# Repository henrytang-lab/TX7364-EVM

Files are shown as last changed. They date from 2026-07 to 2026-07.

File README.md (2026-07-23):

The TX7364EVM is used for the evaluation of TX7364 
device under various drive strength, different voltage 
levels and different modes of the device. The EVM 
contains all necessary control signals and on-board 
power generation, which greatly reduces the need 
for external equipment. The evaluation system also 
includes GUI software for Microsoft® Windows® for 
easily programming various modes and patterns into 
the device.
Features
• Allows control of TX7364 device using simple GUI 
via USB
• B-mode or CW mode of transmit can be 
programmed
• Multiple pattern and Delay profiles can be stored, 
and user can switch between them easily in GUI
• Clock and Sync generator present on board
• Sync frequency can be changed using onboard 
potentiometer
• Option to give external sync
• Uses CMOS serial programming interface
• Error flag register to detect faulty conditions and 
automatic thermal shutdown
• Evaluate Transmit Performance with 100pF||1kΩ 
load



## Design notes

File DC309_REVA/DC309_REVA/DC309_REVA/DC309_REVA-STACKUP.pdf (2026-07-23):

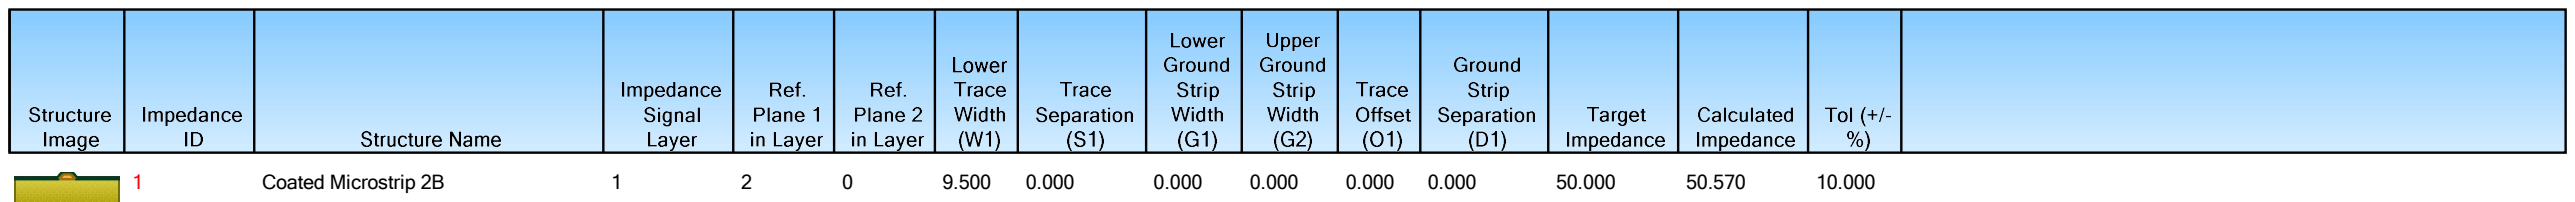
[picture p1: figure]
Coated Microstrip 2B

StackName: Master
Version:
Date: 17-05-2022
Author:
Department:
Site:
Associated Documents: | Revision: | Modification: | Date of Revision: | Editor

Page
1/2
Copyright © | Print style & presentation copyright © Polar Instruments Ltd
Electra | Liquid PhotoImageable Mask | SolderMask | 2.000 | 4.100
1 | Copper Foil | Copper | 1.881 | 100.000 | 1, 2
ISOLA | ISOLA-370HR | PrePreg 2113 | FR4 | 3.405 | 4.040
ISOLA | ISOLA-370HR | PrePreg 1080 | FR4 | 2.649 | 3.900
2 | 0.700 | 65.000
ISOLA | ISOLA-370HR | Core | FR4 | 5.000 | 4.040
3 | 0.700 | 35.000 | 3, 4
ISOLA | ISOLA-370HR | PrePreg 1080 | FR4 | 2.406 | 3.900
ISOLA | ISOLA-370HR | PrePreg 1080 | FR4 | 2.406 | 3.900
4 | 0.700 | 65.000
ISOLA | ISOLA-370HR | Core | FR4 | 5.000 | 4.040
5 | 0.700 | 35.000 | 5, 6
ISOLA | ISOLA-370HR | PrePreg 1080 | FR4 | 2.406 | 3.900
ISOLA | ISOLA-370HR | PrePreg 1080 | FR4 | 2.406 | 3.900
6 | 0.700 | 65.000
ISOLA | ISOLA-370HR | Core | FR4 | 4.000 | 4.300
7 | 0.700 | 65.000
ISOLA | ISOLA-370HR | PrePreg 1080 | FR4 | 2.406 | 3.900
ISOLA | ISOLA-370HR | PrePreg 1080 | FR4 | 2.406 | 3.900
8 | 0.700 | 35.000 | 7, 8
ISOLA | ISOLA-370HR | Core | FR4 | 5.000 | 4.040
9 | 0.700 | 65.000
ISOLA | ISOLA-370HR | PrePreg 1080 | FR4 | 2.406 | 3.900
ISOLA | ISOLA-370HR | PrePreg 1080 | FR4 | 2.406 | 3.900
10 | 0.700 | 35.000 | 9, 10
ISOLA | ISOLA-370HR | Core | FR4 | 5.000 | 4.040
11 | 0.700 | 65.000
ISOLA | ISOLA-370HR | PrePreg 1080 | FR4 | 2.649 | 3.900
ISOLA | ISOLA-370HR | PrePreg 2113 | FR4 | 3.405 | 4.040
12 | Copper Foil | Copper | 1.881 | 100.000 | 11, 12
Electra | Liquid PhotoImageable Mask | SolderMask | 2.000 | 4.100 ⁷⁰.12 | 66.12
2 | Edge Coupled Coated Microstrip 2B | 1 | 2 | 0 | 9.000 | 18.000 | 0.000 | 0.000 | 0.000 | 0.000 | 100.000 | 98.110 | 10.000

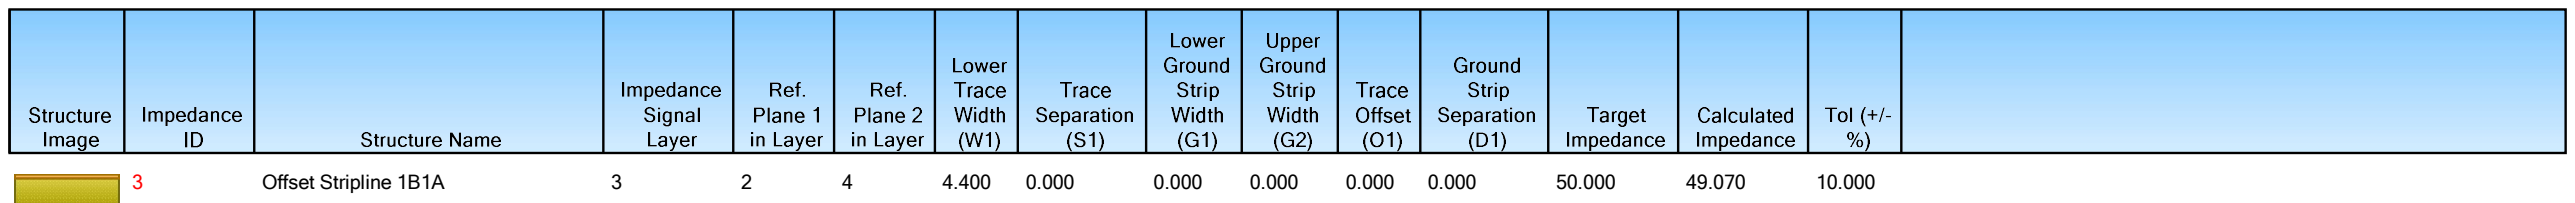
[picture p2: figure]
Offset Stripline 1B1A

StackName:
Version:
Date: 17-05-2022
Author:
Department:
Site:
Associated Documents: | Revision: | Modification: | Date of Revision: | Editor

Page
2/2
Copyright © | Print style & presentation copyright © Polar Instruments Ltd
4 | Edge Coupled Offset Stripline 1B1A | 3 | 2 | 4 | 4.000 | 8.000 | 0.000 | 0.000 | 0.000 | 0.000 | 100.000 | 98.650 | 10.000
5 | Offset Stripline 1B1A | 5 | 4 | 6 | 4.400 | 0.000 | 0.000 | 0.000 | 0.000 | 0.000 | 50.000 | 49.070 | 10.000
6 | Edge Coupled Offset Stripline 1B1A | 5 | 4 | 6 | 4.000 | 8.000 | 0.000 | 0.000 | 0.000 | 0.000 | 100.000 | 98.650 | 10.000
7 | Edge Coupled Offset Stripline 1B1A | 8 | 7 | 9 | 4.000 | 8.000 | 0.000 | 0.000 | 0.000 | 0.000 | 100.000 | 98.650 | 10.000
8 | Offset Stripline 1B1A | 8 | 7 | 9 | 4.400 | 0.000 | 0.000 | 0.000 | 0.000 | 0.000 | 50.000 | 49.070 | 10.000
9 | Edge Coupled Offset Stripline 1B1A | 10 | 9 | 11 | 4.000 | 8.000 | 0.000 | 0.000 | 0.000 | 0.000 | 100.000 | 98.650 | 10.000
10 | Offset Stripline 1B1A | 10 | 9 | 11 | 4.400 | 0.000 | 0.000 | 0.000 | 0.000 | 0.000 | 50.000 | 49.070 | 10.000
11 | Edge Coupled Coated Microstrip 2B | 12 | 11 | 0 | 9.000 | 18.000 | 0.000 | 0.000 | 0.000 | 0.000 | 100.000 | 98.110 | 10.000
12 | Coated Microstrip 2B | 12 | 11 | 0 | 9.500 | 0.000 | 0.000 | 0.000 | 0.000 | 0.000 | 50.000 | 50.570 | 10.000
1 | 12 | 1 | Mechanical PTH

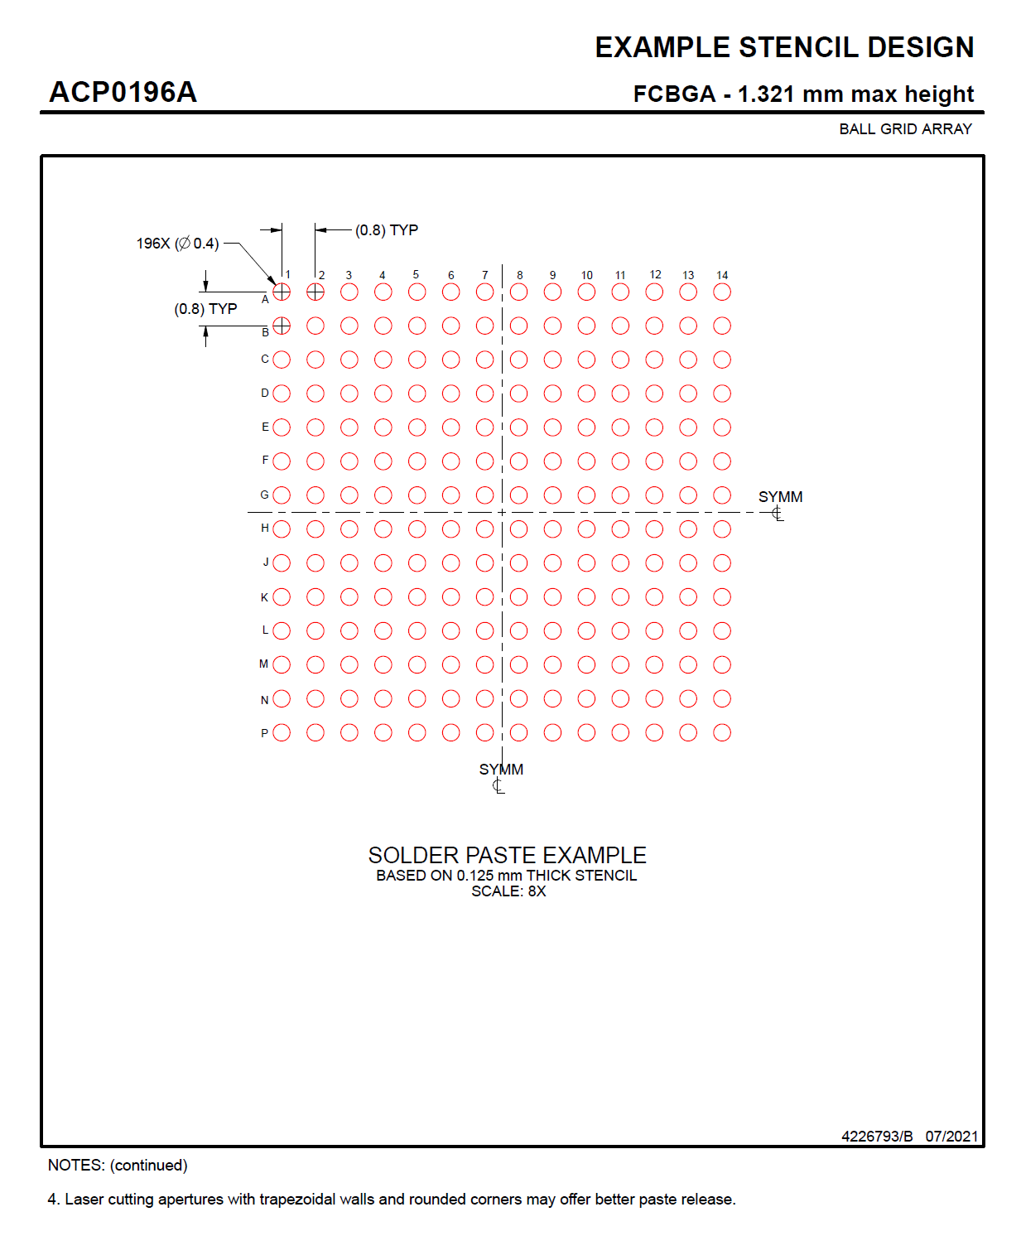
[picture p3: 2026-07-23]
Stencil_Design.PNG

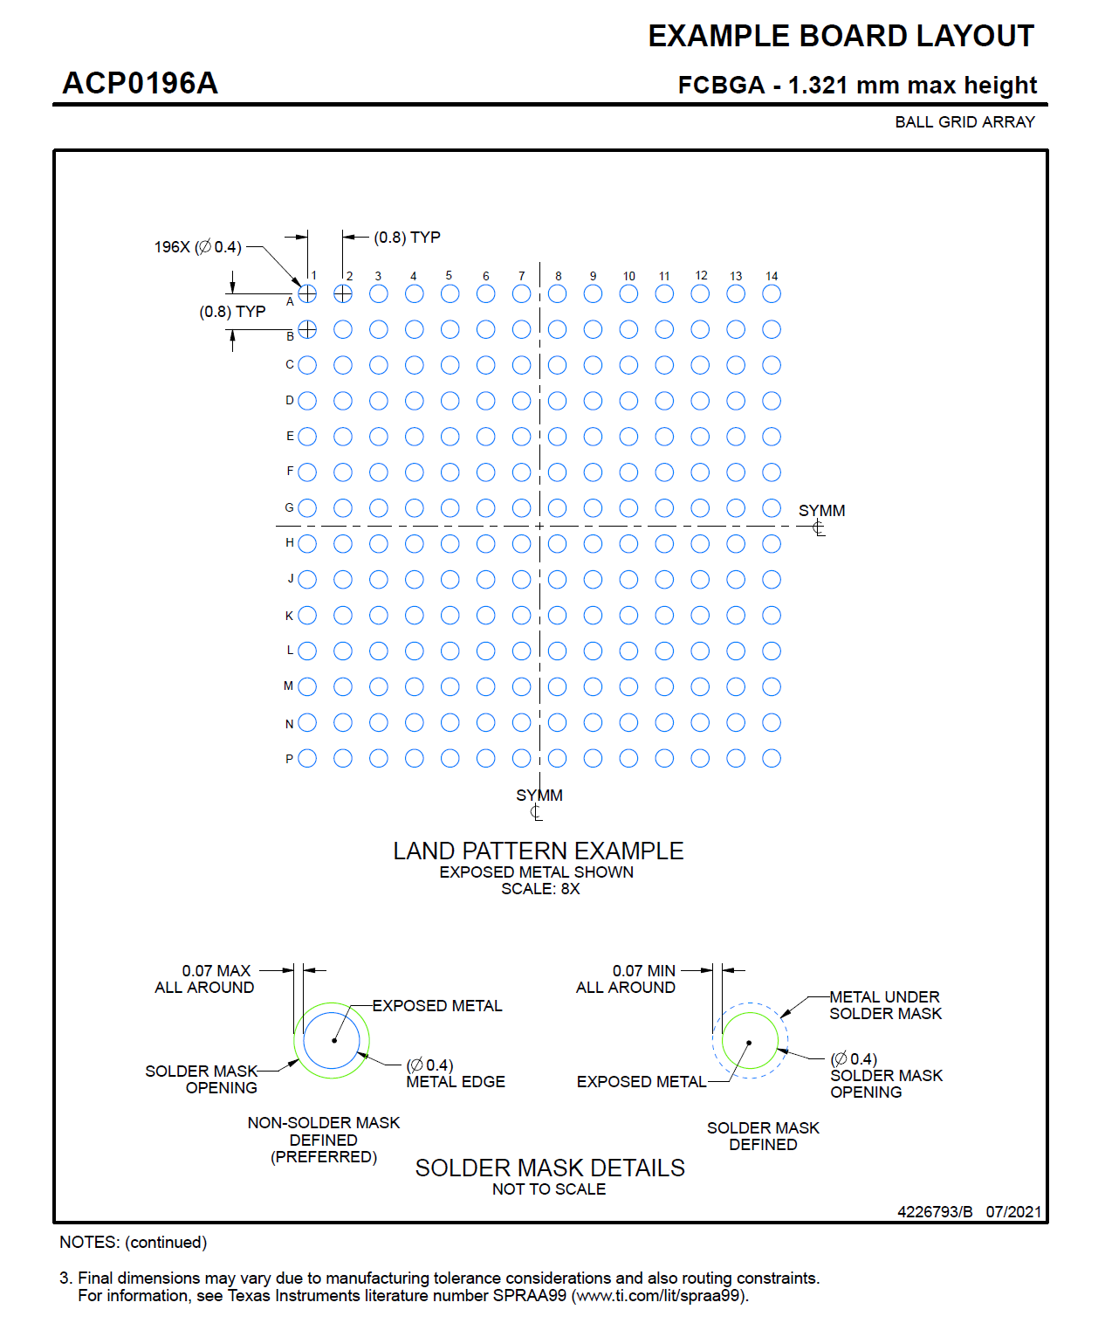
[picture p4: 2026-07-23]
Example_Board_Layout.PNG

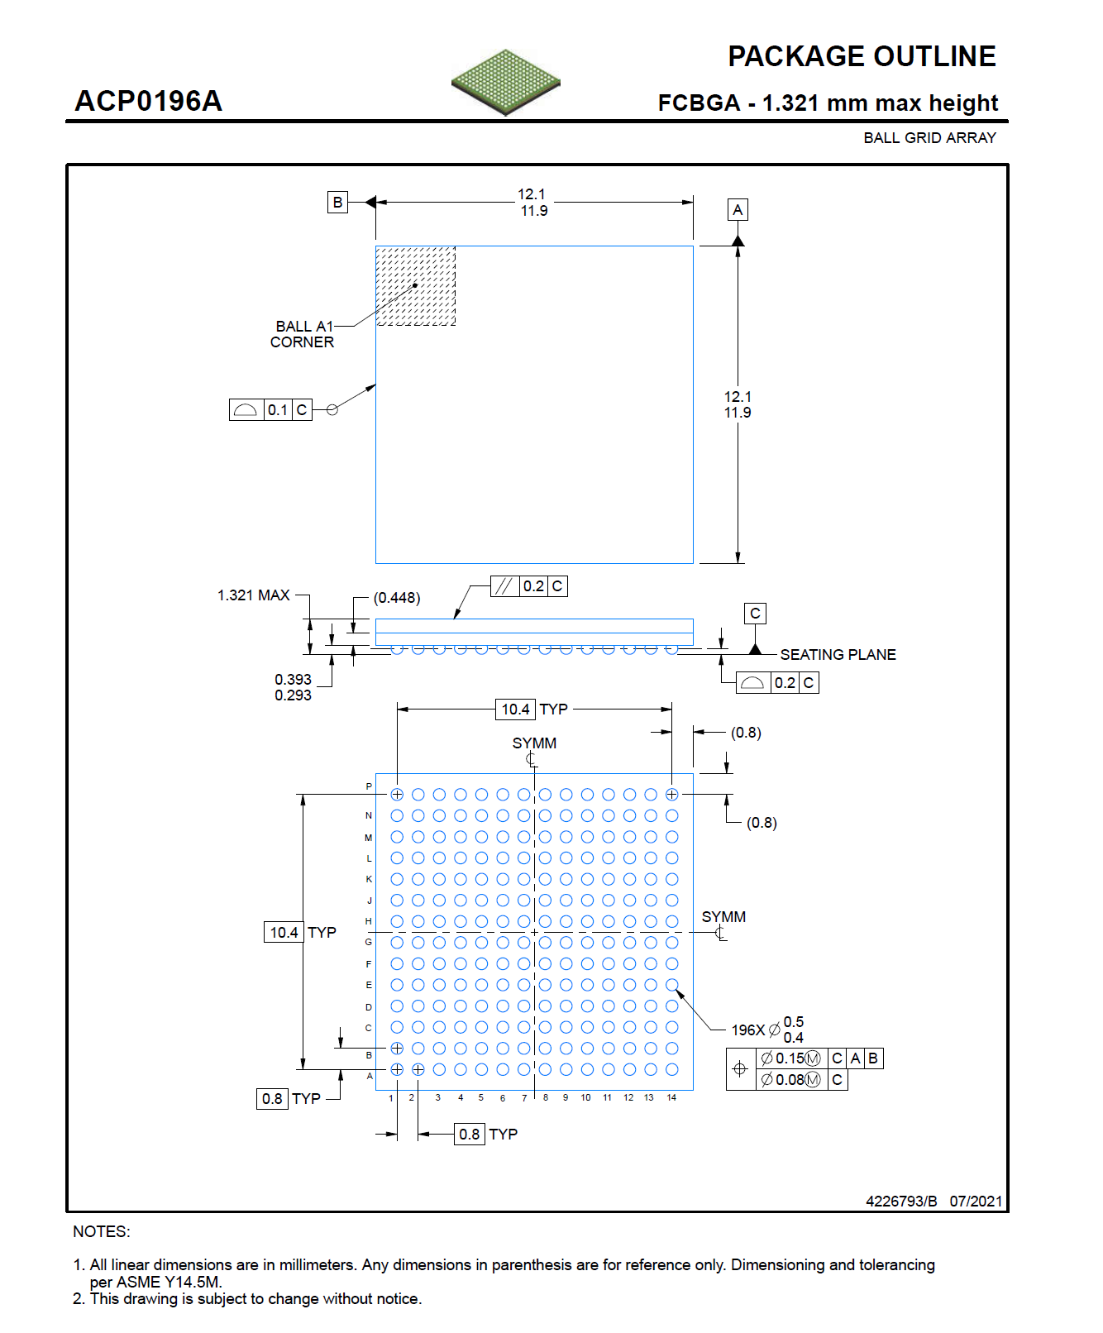
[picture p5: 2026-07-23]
Package_Outline.PNG

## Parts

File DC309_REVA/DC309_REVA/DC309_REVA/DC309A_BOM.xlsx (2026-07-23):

Filename: | #VALUE! |  |  |  | DC309
Variant: | Compact |  |  |  | A
Generated: | 2/14/2024 12:07 PM
TID #: | N/A |  |  |  | DC309 REV A Bill of Materials
Item # | Designator | Quantity | Value | PartNumber | Manufacturer | Description | PackageReference
1 | !PCB1 | 1 |  | DC309 | Any | Printed Circuit Board
2 | C1, C211, C212, C285, C286 | 5 | 0.1uF | GRM155R71C104KA88D | MuRata | CAP, CERM, 0.1 uF, 16 V, +/- 10%, X7R, 0402 | 0402
3 | C2, C5, C6, C22, C71, C72, C73, C74, C75, C76, C77, C78, C79, C80, C81, C82, C83, C84, C86, C87, C88, C89, C90, C91, C92, C93, C94, C95, C96, C97, C98, C174, C175, C177, C178, C179, C180, C181, C182, C183, C184, C185, C186, C187, C188, C189, C190, C191, C193, C194, C195, C196, C197, C198, C199, C200, C201, C202, C203, C204, C205, C207, C213, C215 | 64 | 20pF | C0402C200J5GACTU | Kemet | CAP, CERM, 20 pF, 50 V, +/- 5%, C0G/NP0, 0402 | 0402
4 | C3, C7 | 2 | 10uF | 200LLE10MEFC8X11.5 | Rubycon | CAP, AL, 10 uF, 200 V, +/- 20%, TH | RCAP_8x11.5mm
5 | C4, C8 | 2 | 0.1uF | C1206C104K2RACTU | Kemet | CAP, CERM, 0.1 uF, 200 V, +/- 10%, X7R, 1206 | 1206
6 | C9, C20 | 2 | 10uF | EEE-FK1V100R | Panasonic | CAP, AL, 10 uF, 35 V, +/- 20%, 0.7 ohm, AEC-Q200 Grade 2, SMD | SMT Radial C
7 | C10, C14, C16, C18, C21, C23, C31, C35, C36, C46, C50, C53, C99, C100, C103, C104, C105, C106, C107, C120, C126, C127, C128, C136, C138, C149, C150, C161, C167, C168, C171, C250, C279, C280, C283 | 35 | 0.1uF | 0402YC104KAT2A | AVX | CAP, CERM, 0.1 uF, 16 V, +/- 10%, X7R, 0402 | 0402
8 | C11, C12, C13, C37, C170 | 5 | 4.7pF | 06035A4R7CAT2A | AVX | CAP, CERM, 4.7 pF, 50 V, +/- 5%, C0G/NP0, 0603 | 0603
9 | C15, C17, C19, C49, C172 | 5 | 4.7uF | C0805C475K3PACTU | Kemet | CAP, CERM, 4.7 uF, 25 V, +/- 10%, X5R, 0805 | 0805
10 | C24, C70, C85, C151, C153, C155, C157, C176, C192, C206, C208, C209, C210, C214, C216, C217, C218, C219, C220, C221, C222, C223, C224, C225, C226, C227, C228, C229, C230, C231, C232, C233, C234, C235, C236, C237, C238, C239, C240, C241, C242, C243, C244, C245, C246, C247, C248, C249, C251, C252, C253, C254, C255, C256, C257, C258, C259, C260, C261, C262, C263, C264, C265, C266 | 64 | 100pF | AC0603JRNPOYBN101 | Yageo | CAP, CERM, 100 pF, 250 V,+/- 5%, C0G/NP0, AEC-Q200 Grade 1, 0603 | 0603
11 | C25 | 1 | 10uF | GRM188R60J106ME47D | MuRata | CAP, CERM, 10 uF, 6.3 V, +/- 20%, X5R, 0603 | 0603
12 | C26, C27 | 2 | 0.01uF | 520L103KT16T | AT Ceramics | CAP, CERM, 0.01 uF, 16 V, +/- 10%, X7R, 0402 | 0402
13 | C28, C38, C39, C40, C41, C42, C43, C44, C57, C58, C59, C60, C61, C62, C66, C67 | 16 | 0.1uF | C2012X7T2E104K125AA | TDK | CAP, CERM, 0.1 uF, 250 V, +/- 10%, X7T, 0805 | 0805
14 | C29, C166, C169, C277 | 4 | 0.1uF | C1005X5R0J104K050BA | TDK | CAP, CERM, 0.1 uF, 6.3 V, +/- 10%, X5R, 0402 | 0402
15 | C30, C32, C33, C129 | 4 | 4.7uF | CL05A475MP5NRNC | Samsung Electro-Mechanics | CAP, CERM, 4.7 uF, 10 V, +/- 20%, X5R, 0402 | 0402
16 | C45, C47, C48, C51, C52, C54, C55, C56, C68, C69 | 10 | 0.1uF | C0603X6S1C104K030BC | TDK | CAP, CERM, 0.1 uF, 16 V, +/- 10%, X6S, 0201 | 0201
17 | C140, C141 | 2 | 18pF | 06035A180JAT2A | AVX | CAP, CERM, 18 pF, 50 V, +/- 5%, C0G/NP0, 0603 | 0603
18 | C267 | 1 | 6.8pF | CC0603CRNPO0BN6R8 | Yageo | CAP, CERM, 6.8 pF, 100 V,+/- 3.7%, C0G/NP0, 0603 | 0603
19 | C278 | 1 | 0.012uF | GRM155R71C123KA01D | MuRata | CAP, CERM, 0.012 uF, 16 V, +/- 10%, X7R, 0402 | 0402
20 | C281 | 1 | 100pF | 0603ZC101KAT2A | AVX | CAP, CERM, 100 pF, 10 V, +/- 10%, X7R, 0603 | 0603
21 | C282 | 1 | 0.47uF | 04026D474KAT2A | AVX | CAP, CERM, 0.47 uF, 6.3 V, +/- 10%, X5R, 0402 | 0402
22 | D1, D4, D9, D10, D11, D12, D13, D17 | 8 | Red | CMD17-21SRC/TR8 | Visual Communications Company, LLC | LED, Red, SMD | 2x1.25mm
23 | D3, D6 | 2 | 110V | UDZLVTE-17110 | Rohm | Diode, Zener, 110 V, 200 mW, SOD-323F | SOD-323F
24 | D7, D8 | 2 | 6V | MMSZ5233B-7-F | Diodes Inc. | Diode, Zener, 6 V, 500 mW, SOD-123 | SOD-123
25 | FB1 | 1 | 120 ohm | BLM18SG121TN1D | MuRata | Ferrite Bead, 120 ohm @ 100 MHz, 3 A, 0603 | 0603
26 | FID1, FID2, FID3, FID4, FID5, FID6 | 6 |  | N/A | N/A | Fiducial mark. There is nothing to buy or mount. | N/A
27 | H1, H2, H3, H4 | 4 |  | NY PMS 440 0025 PH | B&F Fastener Supply | Machine Screw, Round, #4-40 x 1/4, Nylon, Philips panhead | Screw
28 | H5, H6, H7, H8 | 4 |  | 1902C | Keystone | Standoff, Hex, 0.5"L #4-40 Nylon | Standoff
29 | H9 | 1 |  | AK67421-0.3 | Assman WSW | Cable, USB-A to micro USB-B, 0.3 m
30 | J1, J5, J6, J10 | 4 |  | PPTC252LFBN-RC | Sullins Connector Solutions | Receptacle, 2.54mm, 25x2, Tin, TH | Receptacle, 2.54mm, 25x2, TH
31 | J2, J3 | 2 |  | 1725669 | Phoenix Contact | Terminal Block, 3x1, 2.54 mm, TH | Terminal Block, 3x1, 2.54 mm, TH
32 | J4, J8, J12, J14 | 4 |  | 901-144-8RFX | Amphenol RF | SMA Straight Jack, Gold, 50 Ohm, TH | SMA Straight Jack, TH
33 | J7, J13, J16 | 3 |  | TSW-103-07-G-S | Samtec | Header, 100mil, 3x1, Gold, TH | 3x1 Header
34 | J9 | 1 |  | 67803-8020 | Molex | Connector, Receptacle, USB - mini AB, R/A, SMD | Receptacle, 5-Leads, Body 9.9x9mm, R/A
35 | R3, R6 | 2 | 100k | TNPW1206100KBEEA | Vishay-Dale | RES, 100 k, 0.1%, 0.25 W, AEC-Q200 Grade 1, 1206 | 1206
36 | R7 | 1 | 5.1k | CRCW04025K10JNED | Vishay-Dale | RES, 5.1 k, 5%, 0.063 W, AEC-Q200 Grade 0, 0402 | 0402
37 | R8, R135, R250 | 3 | 18k | CRCW040218K0JNED | Vishay-Dale | RES, 18 k, 5%, 0.063 W, AEC-Q200 Grade 0, 0402 | 0402
38 | R9 | 1 | 11k | CRCW040211K0JNED | Vishay-Dale | RES, 11 k, 5%, 0.063 W, AEC-Q200 Grade 0, 0402 | 0402
39 | R10, R12, R136, R251 | 4 | 10.0k | CRCW040210K0DHEDP | Vishay-Dale | RES, 10.0 k, 0.5%, 0.063 W, AEC-Q200 Grade 0, 0402 | 0402
40 | R11 | 1 | 3.60k | RG1608P-362-B-T5 | Susumu Co Ltd | RES, 3.60 k, 0.1%, 0.1 W, 0603 | 0603
41 | R13, R110, R124, R130 | 4 | 1.0k | CRCW04021K00JNED | Vishay-Dale | RES, 1.0 k, 5%, 0.063 W, AEC-Q200 Grade 0, 0402 | 0402
42 | R14, R15 | 2 | 499 | CRCW0402499RFKED | Vishay-Dale | RES, 499, 1%, 0.063 W, AEC-Q200 Grade 0, 0402 | 0402
43 | R16, R30, R42, R78, R103, R125, R126, R127, R163, R165, R169, R233, R254, R263, R264, R265, R273, R274, R293, R295, R366, R368 | 22 | 0 | ERJ-2GE0R00X | Panasonic | RES, 0, 5%, 0.1 W, AEC-Q200 Grade 0, 0402 | 0402
44 | R17 | 1 | 0.1 | ERJ-L03KF10CV | Panasonic | RES, 0.1, 1%, 0.1 W, AEC-Q200 Grade 1, 0603 | 0603
45 | R18, R22 | 2 | 100 | CRCW0402100RJNED | Vishay-Dale | RES, 100, 5%, 0.063 W, AEC-Q200 Grade 0, 0402 | 0402
46 | R25, R26, R36, R118, R119, R149, R150, R174, R242, R243, R244, R245, R246, R249, R419, R421, R424, R426 | 18 |  | ERJ-2GE0R00X | Panasonic | RES, 0, 5%, 0.1 W, AEC-Q200 Grade 0, 0402 | 0402
47 | R43, R44, R45, R277, R278, R279 | 6 | 100 | ERJ-2GEJ101X | Panasonic | RES, 100, 5%, 0.1 W, AEC-Q200 Grade 0, 0402 | 0402
48 | R46, R47, R48, R49, R50, R51, R53, R54, R55, R56, R57, R58, R59, R60, R63, R64, R68, R69, R70, R71, R75, R76, R80, R81, R82, R83, R84, R85, R87, R90, R93, R94, R95, R96, R97, R98, R99, R101, R102, R106, R107, R117, R121, R159, R237, R238, R239, R255, R256, R257, R258, R259, R260, R261, R281, R282, R287, R288, R289, R291, R328, R343, R349, R359 | 64 | 100 | RG1005P-101-B-T5 | Susumu Co Ltd | RES, 100, 0.1%, 0.063 W, 0402 | 0402
49 | R72, R139, R565 | 3 | 49.9 | TNPW060349R9BEEA | Vishay-Dale | RES, 49.9, 0.1%, 0.1 W, AEC-Q200 Grade 1, 0603 | 0603
50 | R129 | 1 | 12.0k | CRCW040212K0FKED | Vishay-Dale | RES, 12.0 k, 1%, 0.063 W, AEC-Q200 Grade 0, 0402 | 0402
51 | R134 | 1 | 2.2k | CRCW04022K20JNED | Vishay-Dale | RES, 2.2 k, 5%, 0.063 W, AEC-Q200 Grade 0, 0402 | 0402
52 | R137 | 1 | 100 | CRCW0402100RFKED | Vishay-Dale | RES, 100, 1%, 0.063 W, AEC-Q200 Grade 0, 0402 | 0402
53 | R141, R145 | 2 |  | ERJ-3GEYJ100V | Panasonic | Thick Film Resistors - SMD 0603 10ohms 5% AEC-Q200 | 0603
54 | R152, R154, R156, R157, R158, R161, R162, R284, R285 | 9 | 10k | ERJ-2GEJ103X | Panasonic | RES, 10 k, 5%, 0.1 W, AEC-Q200 Grade 0, 0402 | 0402
55 | R167, R168, R170 | 3 | 0.02 | RL0603FR-070R02L | Yageo America | RES, 0.02, 1%, 0.1 W, AEC-Q200 Grade 0, 0603 | 0603
56 | R252, R253, R280 | 3 | 150 | RT0603BRD07150RL | Yageo America | RES, 150, 0.1%, 0.1 W, 0603 | 0603
57 | R266, R267 | 2 | 56.2k | CRCW040256K2FKED | Vishay-Dale | RES, 56.2 k, 1%, 0.063 W, AEC-Q200 Grade 0, 0402 | 0402
58 | R275 | 1 | 1.0k | CRCW04021K00JNED | Vishay-Dale | RES, 1.0 k, 5%, 0.063 W, 0402 | 0402
59 | R296 | 1 | 0 | CRCW04020000Z0ED | Vishay-Dale | RES, 0, 5%, 0.063 W, AEC-Q200 Grade 0, 0402 | 0402
60 | R347, R352, R362, R365, R369, R371, R373, R387, R389, R391, R393, R395, R397, R399, R404, R406, R408, R410, R432, R434, R436, R438, R440, R442, R444, R446, R448, R450, R452, R454, R468, R470, R472, R474, R476, R478, R480, R482, R484, R486, R488, R490, R504, R506, R508, R510, R512, R514, R516, R518, R520, R522, R524, R526, R540, R542, R544, R546, R548, R550, R552, R554, R560, R562 | 64 | 0 | 5106 | Keystone | RES, 0, 1%, 0.5 W, 0805 | 0805
61 | R361 | 1 | 12 | CRCW040212R0JNED | Vishay-Dale | RES, 12, 5%, 0.063 W, AEC-Q200 Grade 0, 0402 | 0402
62 | R363 | 1 | 100kΩ | CT-94EW104 | Nidec Components | 100 kOhms 0.5W, 1/2W PC Pins Through Hole Trimmer Potentiometer Cermet 18.0 Turn Top Adjustment | PTH_POTEN_9MM6_4MM8
63 | R564 | 1 | 1.02k | CRCW12061K02FKEA | Vishay-Dale | RES, 1.02 k, 1%, 0.25 W, AEC-Q200 Grade 0, 1206 | 1206
64 | S1 | 1 |  | EVQ-5PN04K | Panasonic | Switch, SPST-NO, Off-Mom, 0.05 A, 12 VDC, SMD | 6x3.5mm
65 | SH-J1, SH-J2, SH-J3 | 3 |  | QPC02SXGN-RC | Sullins | CONN JUMPER S2 (1 x 2) Position Shunt Connector Black Open Top 0.100" (2.54mm) GoldHORTING .100" GOLD | JUMPER
66 | T1 | 1 |  | ADT4-1WT+ | Minicircuits | RF Transformer, 50 ohm, 2 to 775 MHz, SMT | CD542
67 | TP1, TP2, TP3, TP4, TP5, TP23, TP43, TP50, TP51, TP52 | 10 |  | 5000 | Keystone Electronics | Test Point, Miniature, Red, TH | Red Miniature Testpoint
68 | TP10, TP11, TP12, TP13 | 4 |  | 5001 | Keystone Electronics | Test Point, Miniature, Black, TH | Black Miniature Testpoint
69 | TP18, TP28, TP40, TP41, TP42, TP54 | 6 |  | 5004 | Keystone Electronics | Test Point, Miniature, Yellow, TH | Yellow Miniature Testpoint
70 | U1 | 1 |  | TX7364 | Texas Instruments | TX7364 | FCBGA196
71 | U3, U34, U39 | 3 |  | TPS79901YZUT | Texas Instruments | Single Output High PSRR LDO, 200 mA, Adjustable 1.2 to 6.5 V Output, 2.7 to 6.5 V Input, with Low IQ, 5-pin DSBGA (YZU), -40 to 85 degC, Green (RoHS & no Sb/Br) | YZU0005AEBC
72 | U4 | 1 |  |  | Texas Instruments | CMOS Low-Power Monostable/Astable Multivibrator, D0014A, LARGE T&R | D0014A
73 | U6 | 1 |  | ISO7841DWW | Texas Instruments | High-Immunity, 5.7kVRMS Reinforced Quad-Channel 3/1 Digital Isolator, 100Mbps, DWW0016A (SOIC-16) | DWW0016A
74 | U7 | 1 |  | FT4232H-56Q-TRAY | FTDI | Future Technology Devices International Ltd FT4232H Quad High Speed USB to Multipurpose UART/MPSSE IC, VQFN-56 | VQFN-56
75 | U8 | 1 |  | ISO7840FDWWR | Texas Instruments | High-Performance, 8000-VPK Reinforced Quad-Channel Digital Isolator | SOIC16
76 | U10 | 1 |  | 93LC46BT-I/SN | Microchip | 1K Microwire Compatible Serial EEPROM | SOIC-8
77 | U15 | 1 |  | TPS79901DDCR | Texas Instruments | Single Output High PSRR LDO, 200 mA, Adjustable 1.2 to 6.5 V Output, 2.7 to 6.5 V Input, with Low IQ, 5-pin SOT (DDC), -40 to 85 degC, Green (RoHS & no Sb/Br) | DDC0005A
78 | U18, U35 | 2 |  | SN74AUP1G08DBVT | Texas Instruments | Low-Power Single 2-Input Positive-AND Gate, DBV0005A (SOT-23-5) | DBV0005A
79 | U33 | 1 |  | CDCM1802RGTR | Texas Instruments | Clock Buffer w/Programmable Divider, LVPECL I/O + addl LVCMOS output, RGT0016A (VQFN-16) | RGT0016A
80 | U36 | 1 |  |  | Texas Instruments | Single Schmitt-Trigger Inverter, DBV0005A, LARGE T&R | DBV0005A
81 | U40 | 1 |  | SN74AXC1T45DBVR | Texas Instruments | Single-Bit Dual-Supply Bus Transceiver, DBV0006A (SOT-23-6) | DBV0006A
82 | U41 | 1 |  | SN65LVDS100DGKR | Texas Instruments | 2 Gbps LVDS/LVPECL/CML to LVDS Buffer/Repeater/Translator, DGK0008A (VSSOP-8) | DGK0008A
83 | U42 | 1 |  | SN74AUP2G79DCUR | Texas Instruments | Low-Power Dual Positive-Edge-Triggered D-Type Flip-Flop, DCU0008A (VSSOP-8) | DCU0008A
84 | U44 | 1 |  | SN74AXC4T774RSVR | Texas Instruments | 4 Bit Direction Controlled Level Translator, RSV0016A (UQFN-16) | RSV0016A
85 | Y1 | 1 |  | SG3225VAN 250.000000M-KEGA3 | EPSON | XTAL OSC XO 250.0000MHZ LVDS SMD | XTAL_SMD_3MM2_2MM5
86 | Y2 | 1 |  | ABM3-12.000MHZ-D2Y-T | Abracon Corporation | Crystal, 12 MHz, 18 pF, SMD | ABM3
87 | C34, C63, C124, C125 | 0 | 0.01uF | 520L103KT16T | AT Ceramics | CAP, CERM, 0.01 uF, 16 V, +/- 10%, X7R, 0402 | 0402
88 | C64, C65, C108, C109, C110, C111, C112, C113, C114, C115, C116, C117, C118, C119, C121, C122, C123, C130, C131, C133, C134, C135, C137, C139, C160 | 0 | 0.1uF | 0402YC104KAT2A | AVX | CAP, CERM, 0.1 uF, 16 V, +/- 10%, X7R, 0402 | 0402
89 | C101, C102 | 0 | 5pF | CBR04C509B1GAC | Kemet | CAP, CERM, 5 pF, 100 V,+/- 2%, C0G/NP0, 0402 | 0402
90 | C162, C163, C164, C165 | 0 | 4.7pF | 06035A4R7CAT2A | AVX | CAP, CERM, 4.7 pF, 50 V, +/- 5%, C0G/NP0, 0603 | 0603
91 | J11 | 0 |  | TSW-105-07-F-D | Samtec | Header, 2.54mm, 5x2, Gold, Black, TH | Header, 2.54mm, 5x2, TH
92 | R19, R31, R33, R39, R62, R74, R79, R92, R104, R114 | 0 | 121 | CRCW0402121RFKED | Vishay-Dale | RES, 121, 1%, 0.063 W, AEC-Q200 Grade 0, 0402 | 0402
93 | R20, R29, R122, R123, R140, R144, R146, R147, R148, R151, R173, R236, R247, R248, R420, R422, R423, R425 | 0 |  | ERJ-2GE0R00X | Panasonic | RES, 0, 5%, 0.1 W, AEC-Q200 Grade 0, 0402 | 0402
94 | R21, R35, R66, R89, R108 | 0 | 169 | CRCW0402169RFKED | Vishay-Dale | RES, 169, 1%, 0.063 W, AEC-Q200 Grade 0, 0402 | 0402
95 | R23, R38, R67, R91, R109 | 0 | 100 | CRCW0402100RFKED | Vishay-Dale | RES, 100, 1%, 0.063 W, AEC-Q200 Grade 0, 0402 | 0402
96 | R24, R27, R28, R32, R34, R37, R40, R41, R65, R77, R86, R100, R105, R111, R116, R128, R131, R132, R133, R138, R234, R235, R276 | 0 | 0 | ERJ-2GE0R00X | Panasonic | RES, 0, 5%, 0.1 W, AEC-Q200 Grade 0, 0402 | 0402
97 | R52, R375, R376, R377, R378, R379, R412, R413, R414, R415, R416, R417, R456, R457, R458, R459, R460, R461, R492, R493, R494, R495, R496, R497, R528, R529, R530, R531, R532, R533, R556, R557 | 0 | 1.00k | CRCW25121K00FKEG | Vishay-Dale | RES, 1.00 k, 1%, 1 W, AEC-Q200 Grade 0, 2512 | 2512
98 | R112, R113, R115, R120 | 0 | 100 | CRCW0402100RJNED | Vishay-Dale | RES, 100, 5%, 0.063 W, AEC-Q200 Grade 0, 0402 | 0402
99 | R240, R241 | 0 | 100 | ERJ-2GEJ101X | Panasonic | RES, 100, 5%, 0.1 W, AEC-Q200 Grade 0, 0402 | 0402
100 | R283, R286 | 0 | 10k | ERJ-2GEJ103X | Panasonic | RES, 10 k, 5%, 0.1 W, AEC-Q200 Grade 0, 0402 | 0402
101 | S2, S3 | 0 |  | EVQ-5PN04K | Panasonic | Switch, SPST-NO, Off-Mom, 0.05 A, 12 VDC, SMD | 6x3.5mm
102 | U2 | 0 |  | TLV75801PDBVT | Texas Instruments | Linear Voltage Regulator IC 1 Output 500mA SOT-23-5 | SOT-23-5
103 | U5, U51 | 0 |  | SN74AUC74RGYR | Texas Instruments | Dual Positive-Edge-Triggered D-Type Flip-Flops with Clear and Preset, RGY0014A, LARGE T&R | RGY0014A
104 | U6_1, U14_1, U17_1 | 0 |  | ISO7741DWR | Texas Instruments | High-Speed, Low-Power, Robust EMC Quad-Channel Digital Isolator, DW0016B (SOIC-16) | DW0016B
105 | U8_1 | 0 |  | ISO7740FDWR | Texas Instruments | High-Speed, Low-Power, Robust EMC Quad-Channel Digital Isolator, DW0016B (SOIC-16) | DW0016B
106 | U9 | 0 |  | 5M570ZT100A5N | Altera | IC CPLD 440MC, TQFP-100 | 14x14mm
107 | U11 | 0 |  | SN65LVDT2DBVR | Texas Instruments | Single LVDS Receiver, DBV0005A (SOT-23-5) | DBV0005A
108 | U12 | 0 |  | LMK00304SQ/NOPB | Texas Instruments | 3.1-GHz Differential Clock Buffer/Level Translator, RTV0032A (WQFN-32) | RTV0032A
109 | U13 | 0 |  | LMK61E2-SIAR | Texas Instruments | Ultra-Low Jitter Fully Programmable Oscillator, Integrated EEPROM, +/-50ppm, SIA0008B (QFM-8) | SIA0008B
110 | U14, U17 | 0 |  | ISO7841DWW | Texas Instruments | High-Immunity, 5.7kVRMS Reinforced Quad-Channel 3/1 Digital Isolator, 100Mbps, DWW0016A (SOIC-16) | DWW0016A
111 | U16 | 0 |  | ISO1540QDRQ1 | Texas Instruments | Low-Power Bidirectional I2C Isolators, D0008B (SOIC-8) | D0008B

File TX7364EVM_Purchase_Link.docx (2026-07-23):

Please use this link to purchase the TX7364EVM: https://www.ti.com/store/ti/en/p/product/?p=TX7364EVM&s=626e234v2e55245ex5

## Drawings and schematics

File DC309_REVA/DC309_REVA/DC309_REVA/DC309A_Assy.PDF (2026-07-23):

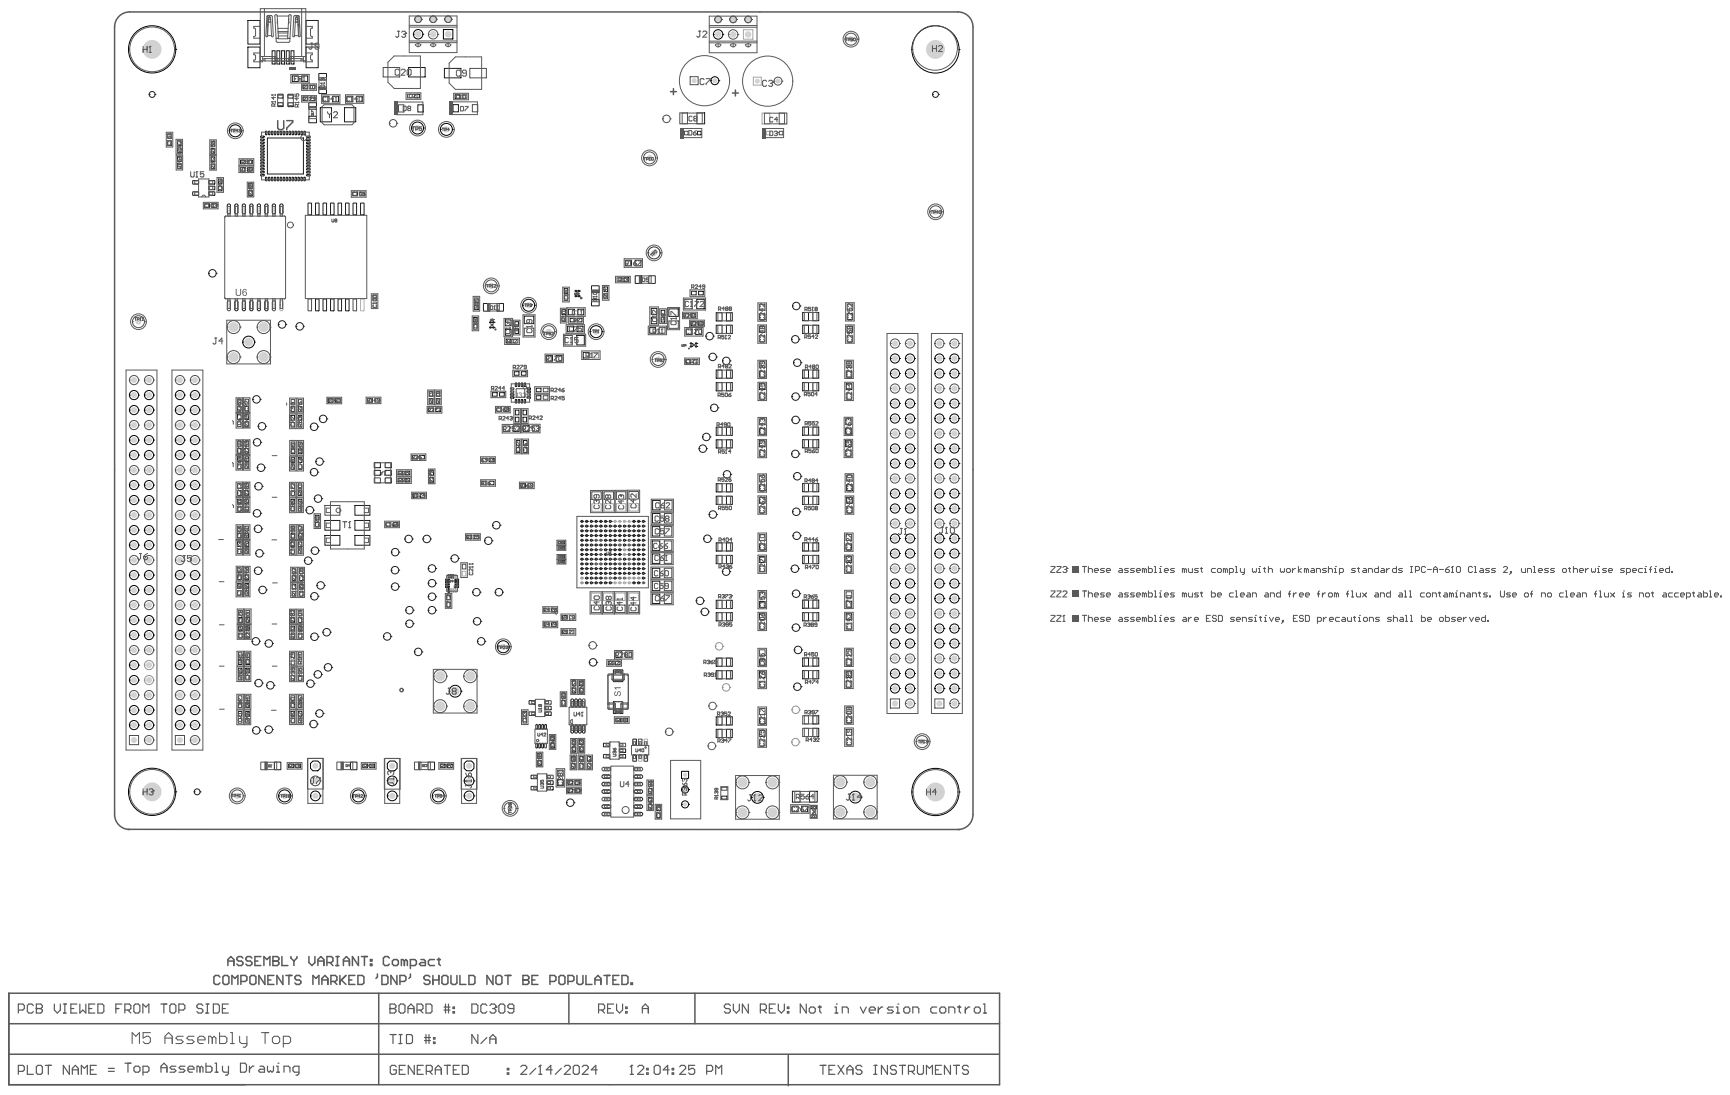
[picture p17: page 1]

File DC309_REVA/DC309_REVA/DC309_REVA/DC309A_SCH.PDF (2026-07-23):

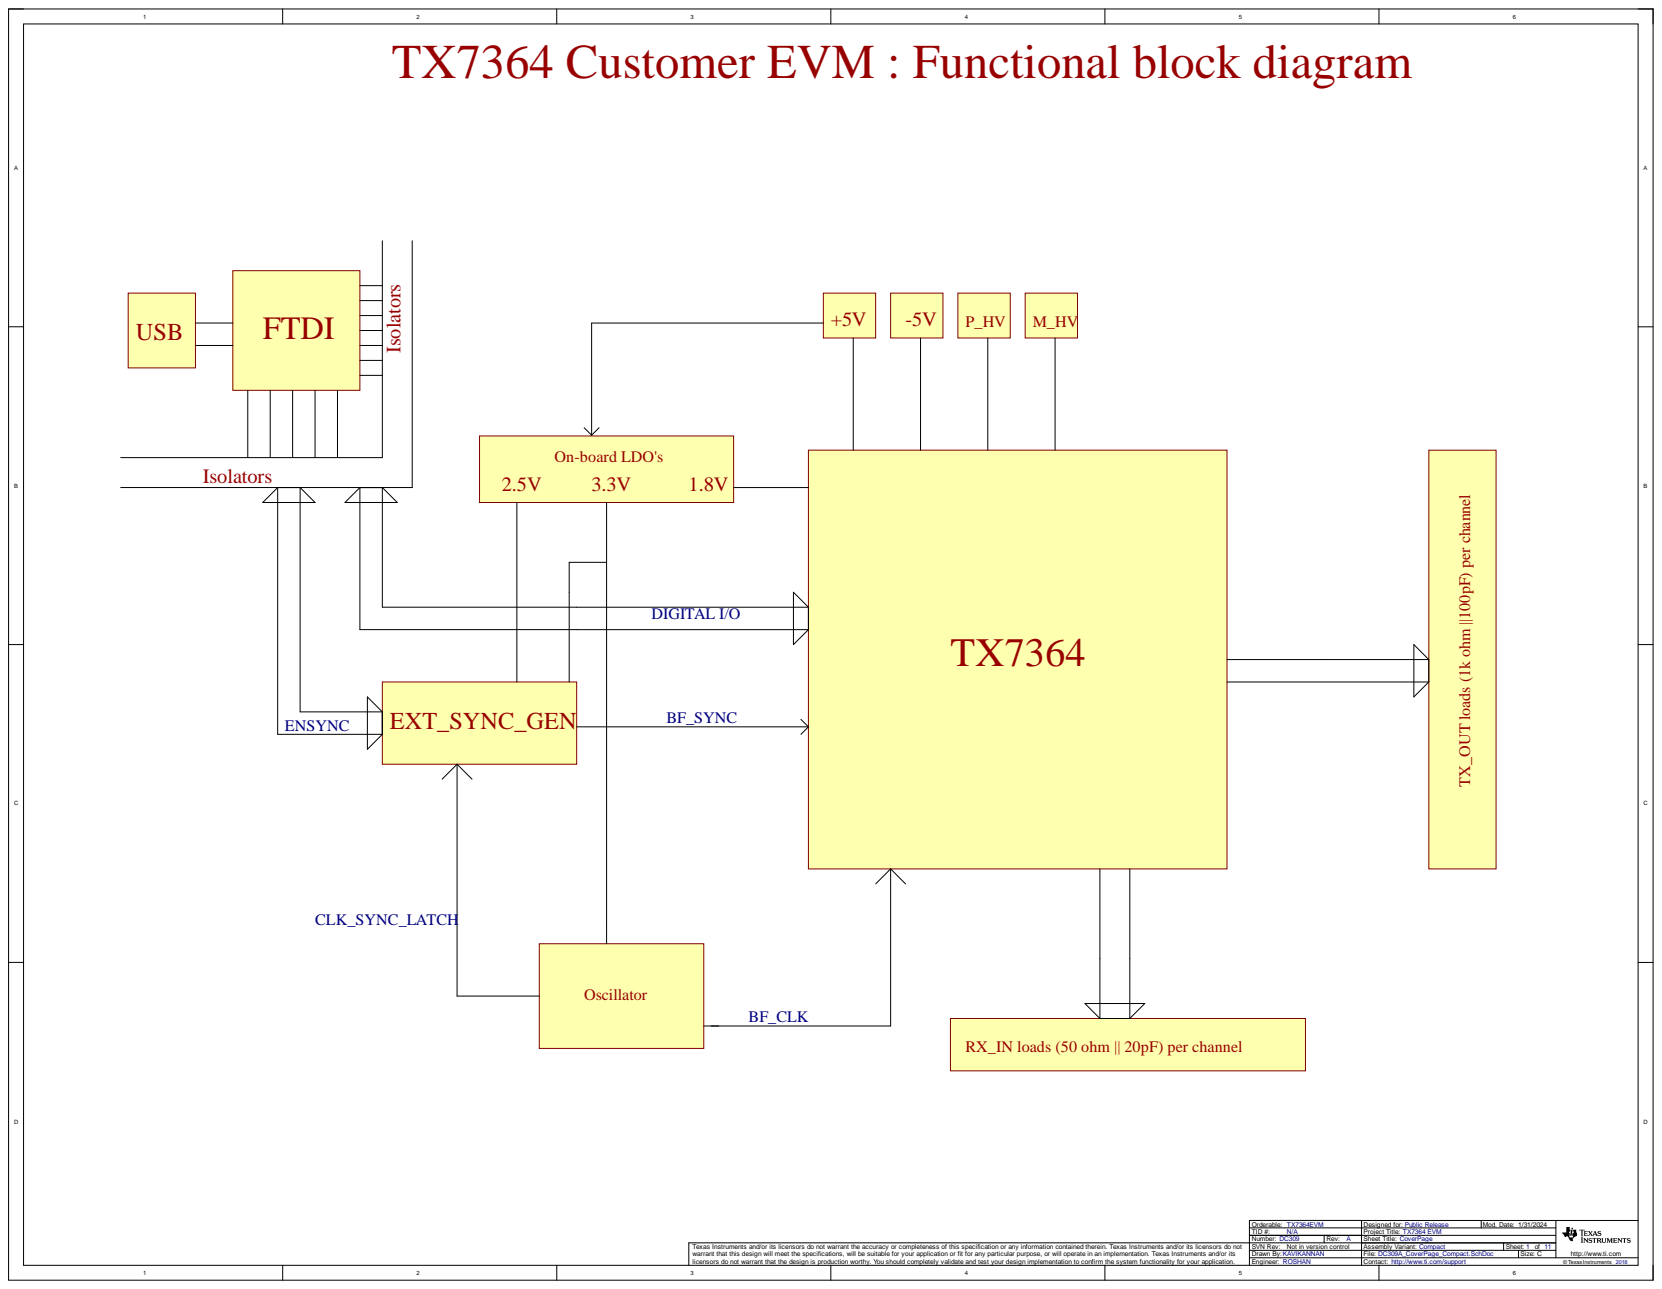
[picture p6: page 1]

TX7364 Customer EVM : Functional block diagram

DIGITAL I/O

BF_SYNC

RX_IN loads (50 ohm || 20pF) per channel

Orderable: TX7364EVM | Designed for: Public Release | Mod. Date: | http://www.ti.com
TID #: N/A | Project Title: TX7364 EVM
Number: DC309 | Rev: A | Sheet Title: CoverPage

Texas Instruments and/or its licensors do not warrant the accuracy or completeness of this specification or any information contained therein. Texas Instruments and/or its licensors do not warrant that this design will meet the specifications, will be suitable for your application or fit for any particular purpose, or will operate in an implementation. Texas Instruments and/or its licensors do not warrant that the design is production worthy. You should completely validate and test your design implementation to confirm the system functionality for your application. | SVN Rev: Not in version control | Assembly Variant: Compact | Sheet: of

Drawn By: KAVIKANNAN | File: DC309A_CoverPage_Compact.SchDoc | Size: C
Engineer: ROSHAN | Contact: http://www.ti.com/support ©Texas Instruments 2018

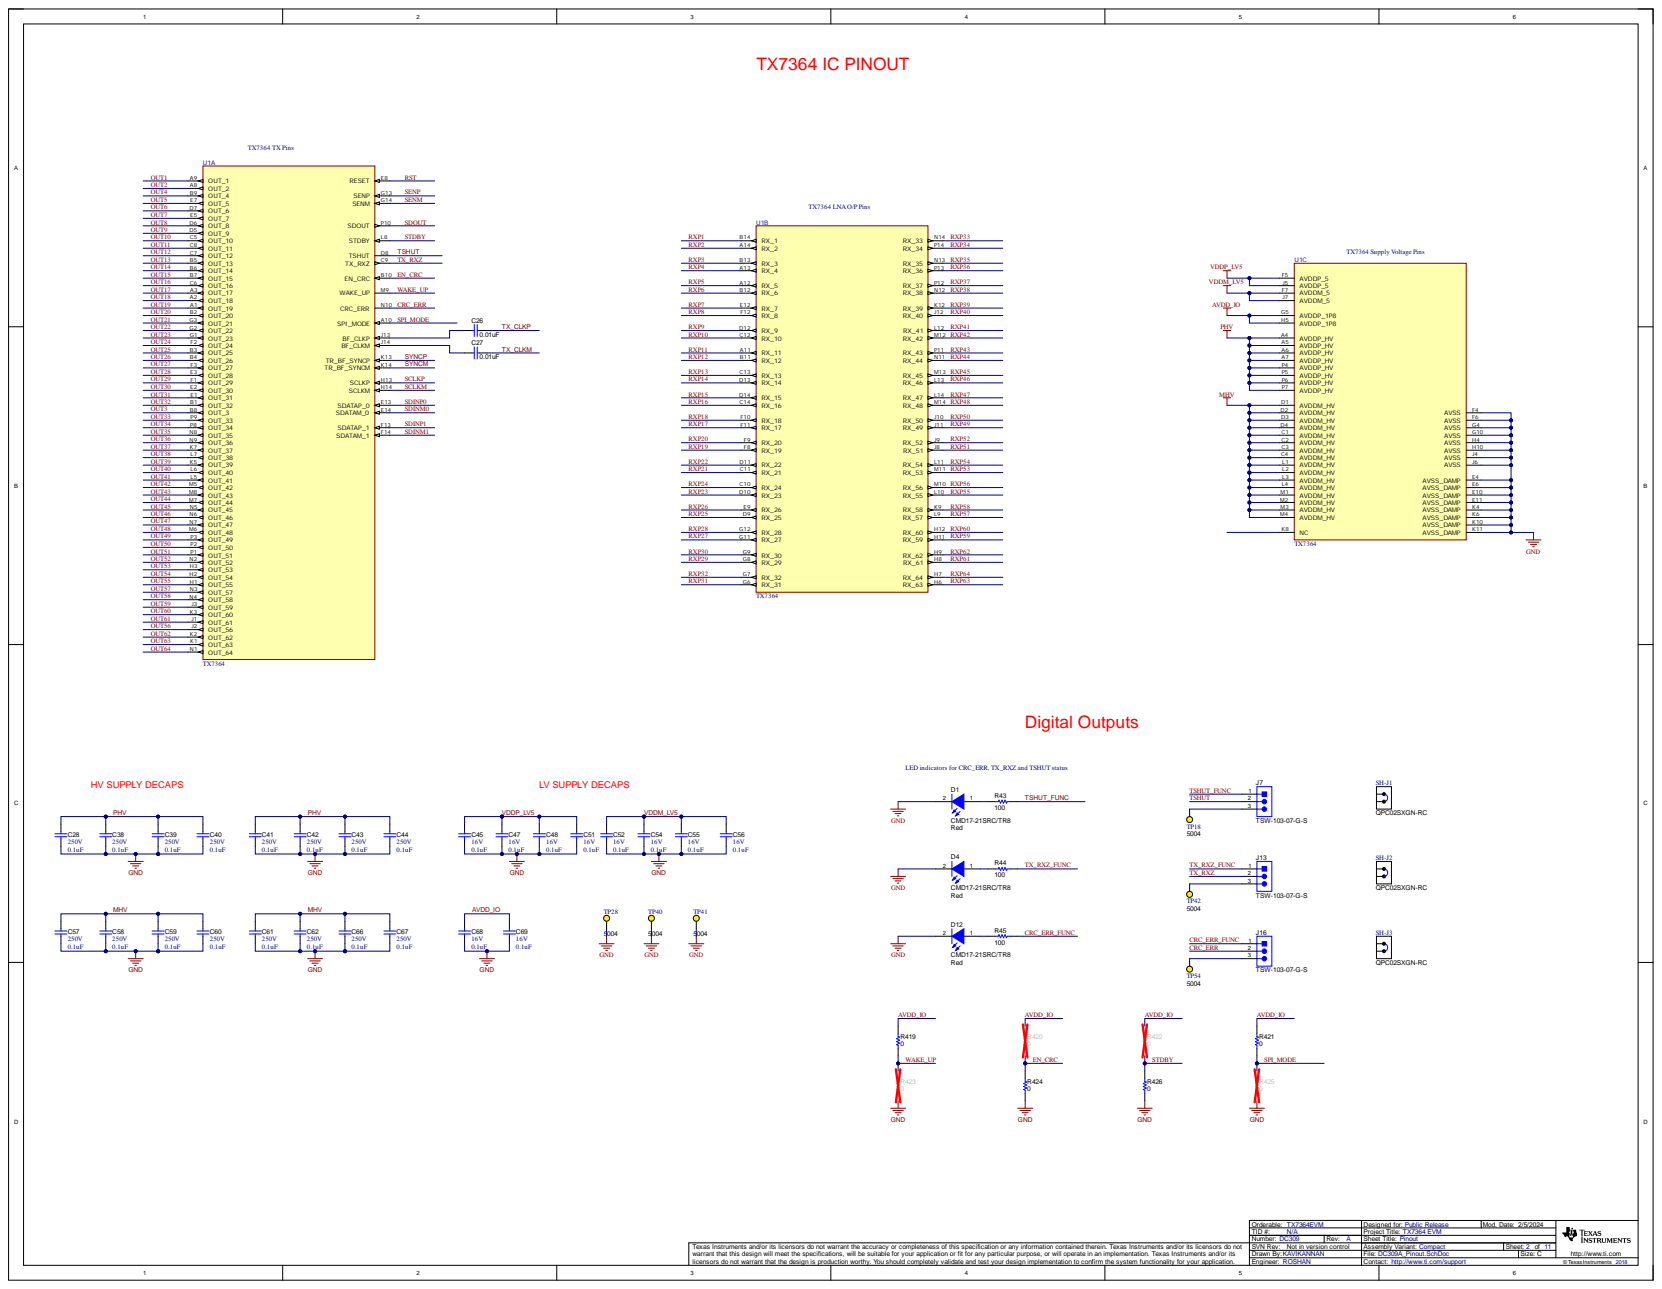
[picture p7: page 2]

LED indicators for CRC_ERR, TX_RXZ and TSHUT status

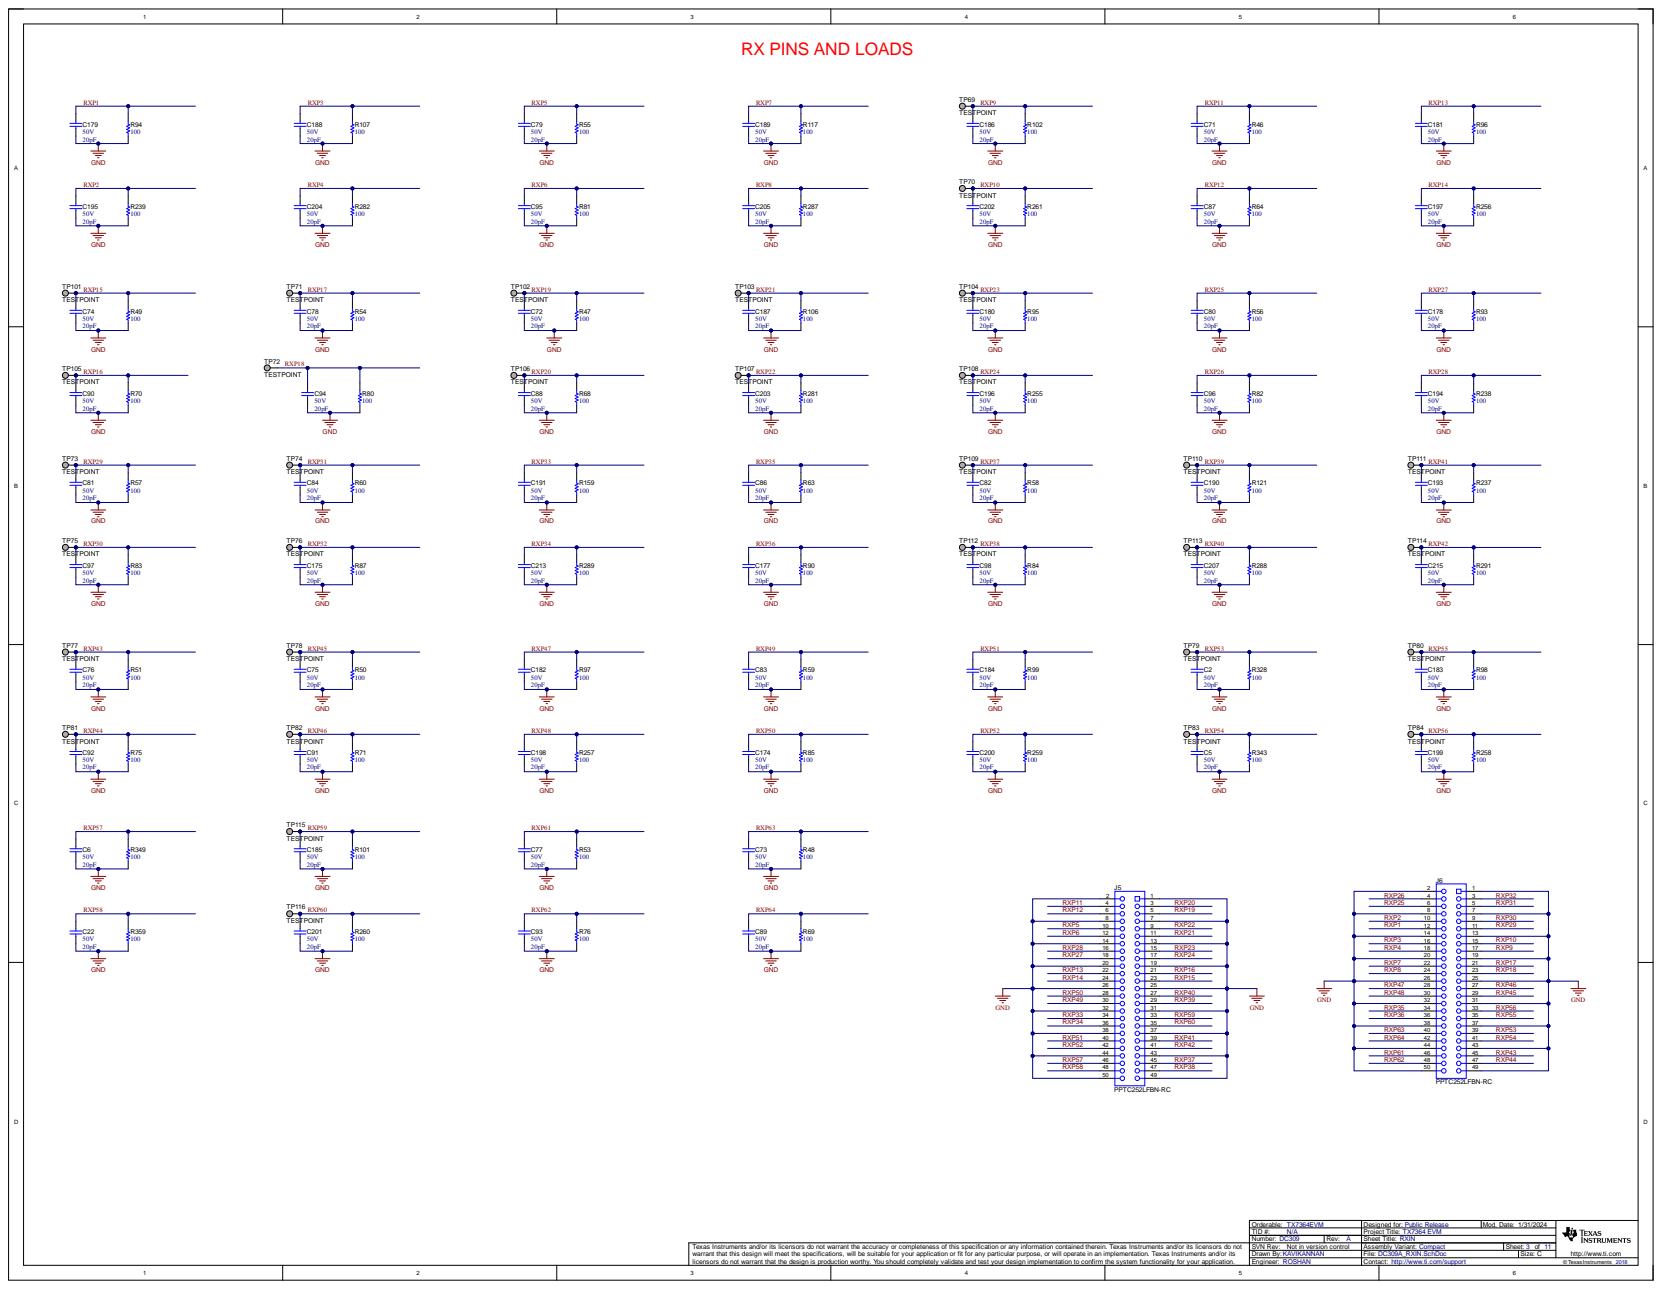
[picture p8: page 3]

RX PINS AND LOADS

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

D r a w n B y : KAV I KA N N A N | F i l e : D C A_ R X I N . S c h D o c | S i z e :

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

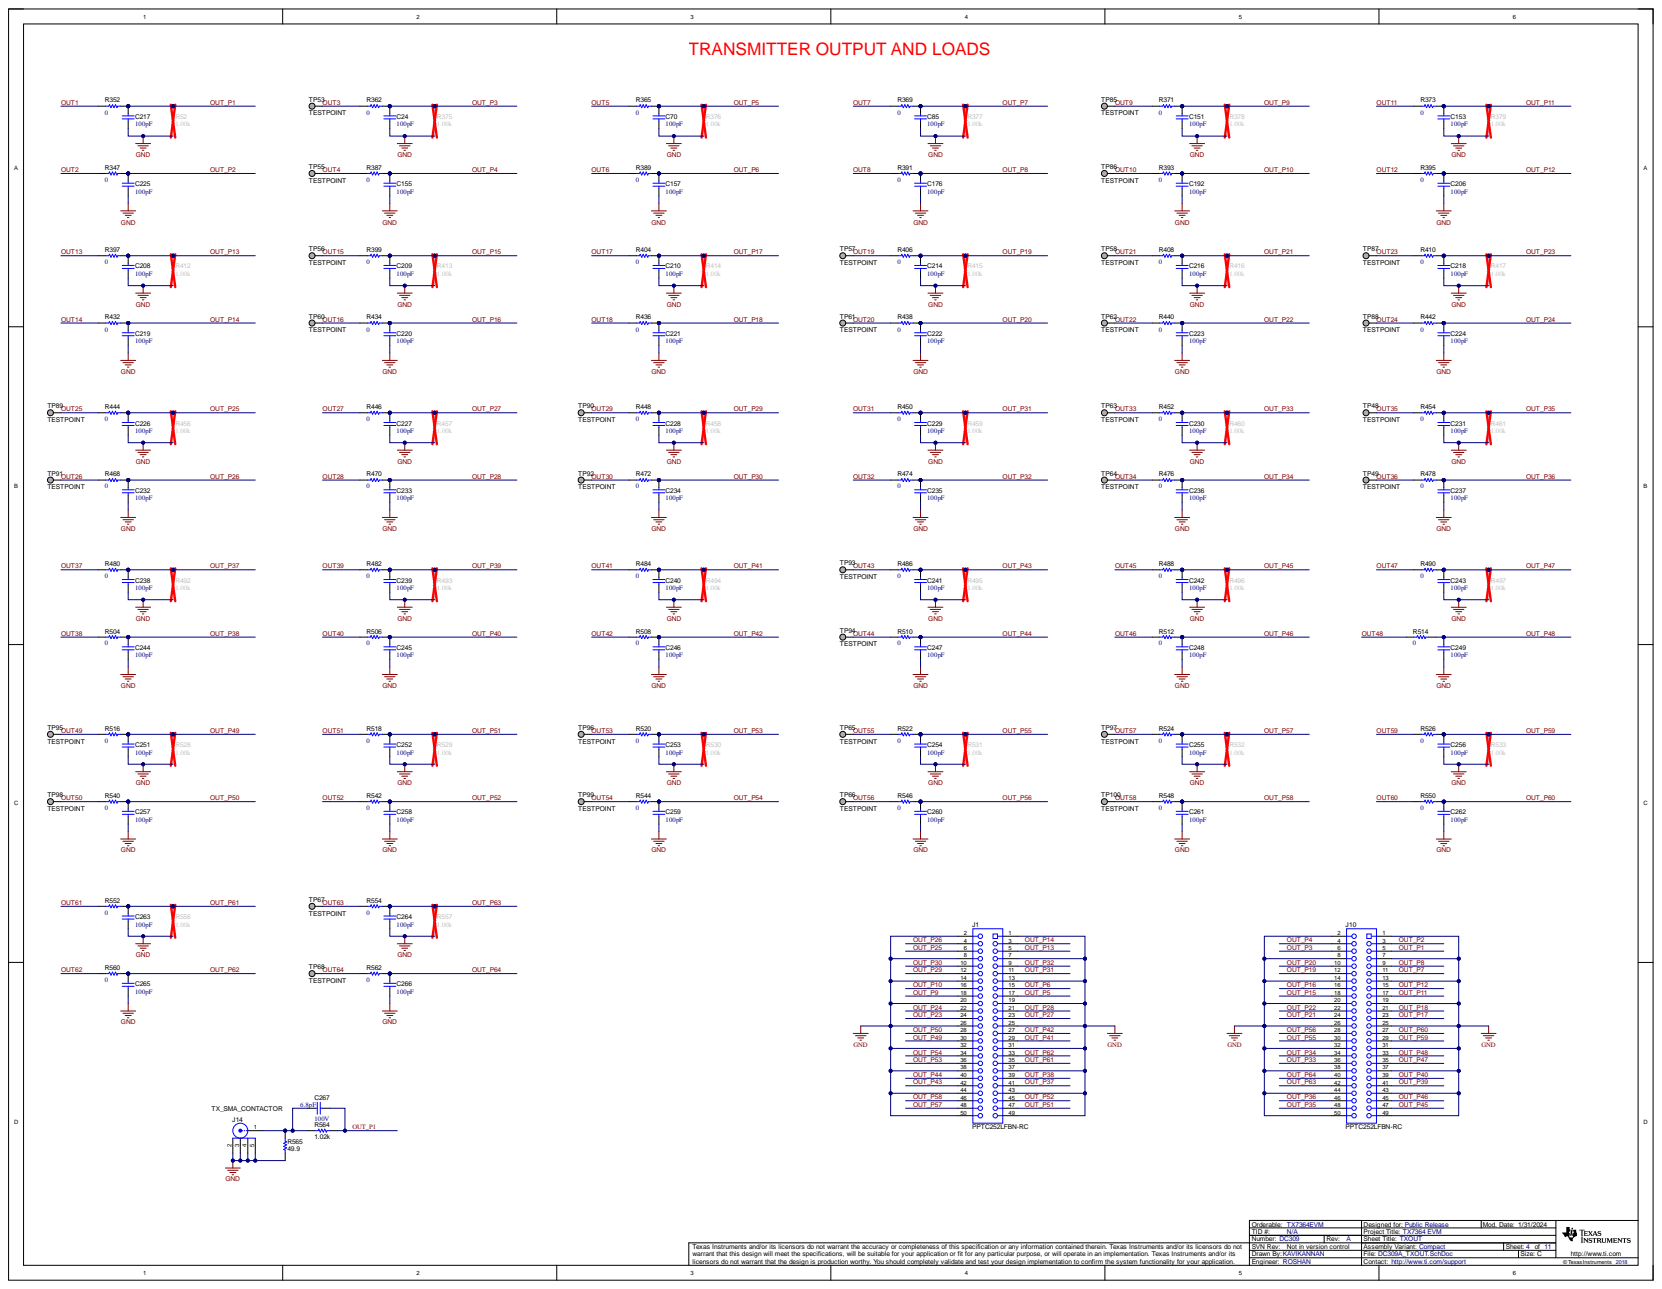
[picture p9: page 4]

TRANSMITTER OUTPUT AND LOADS

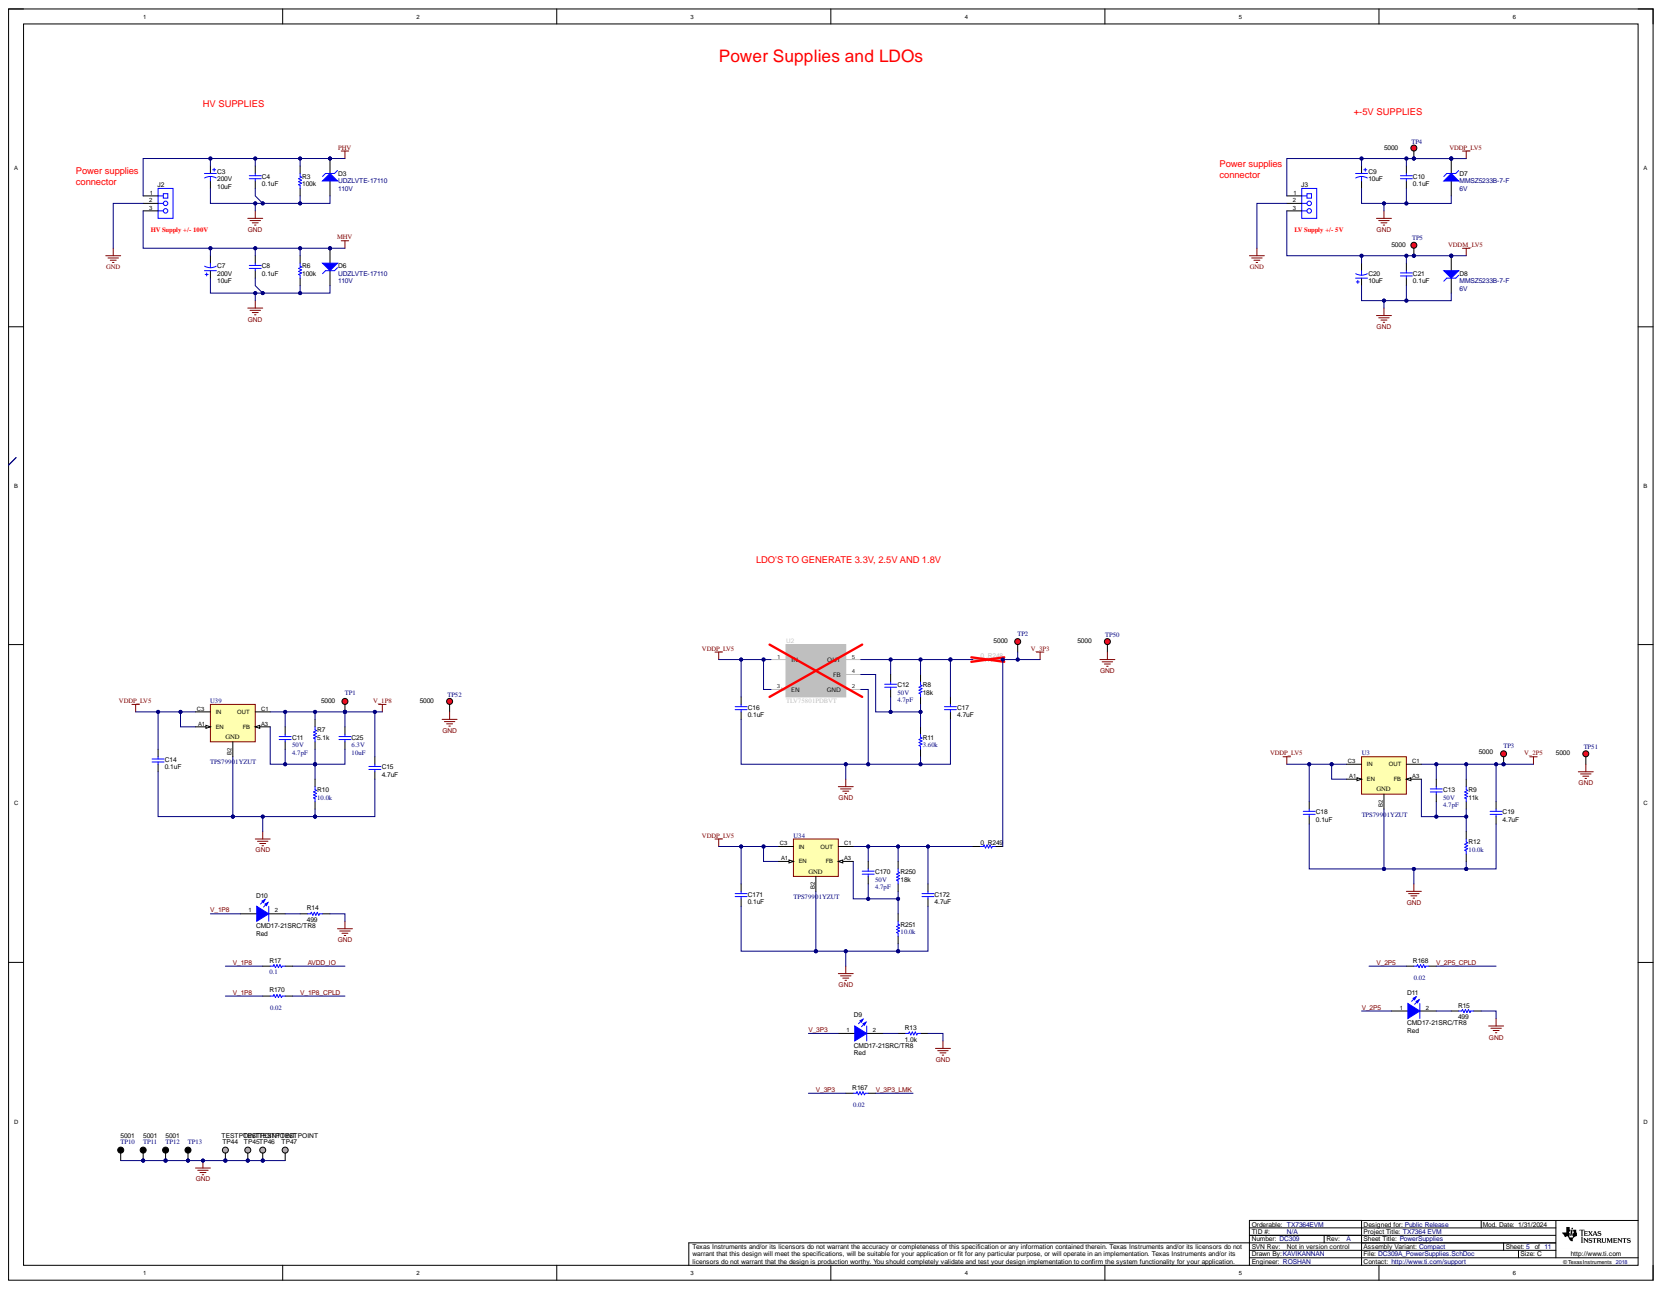
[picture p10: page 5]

Power Supplies and LDOs

LDO'S TO GENERATE 3.3V, 2.5V AND 1.8V

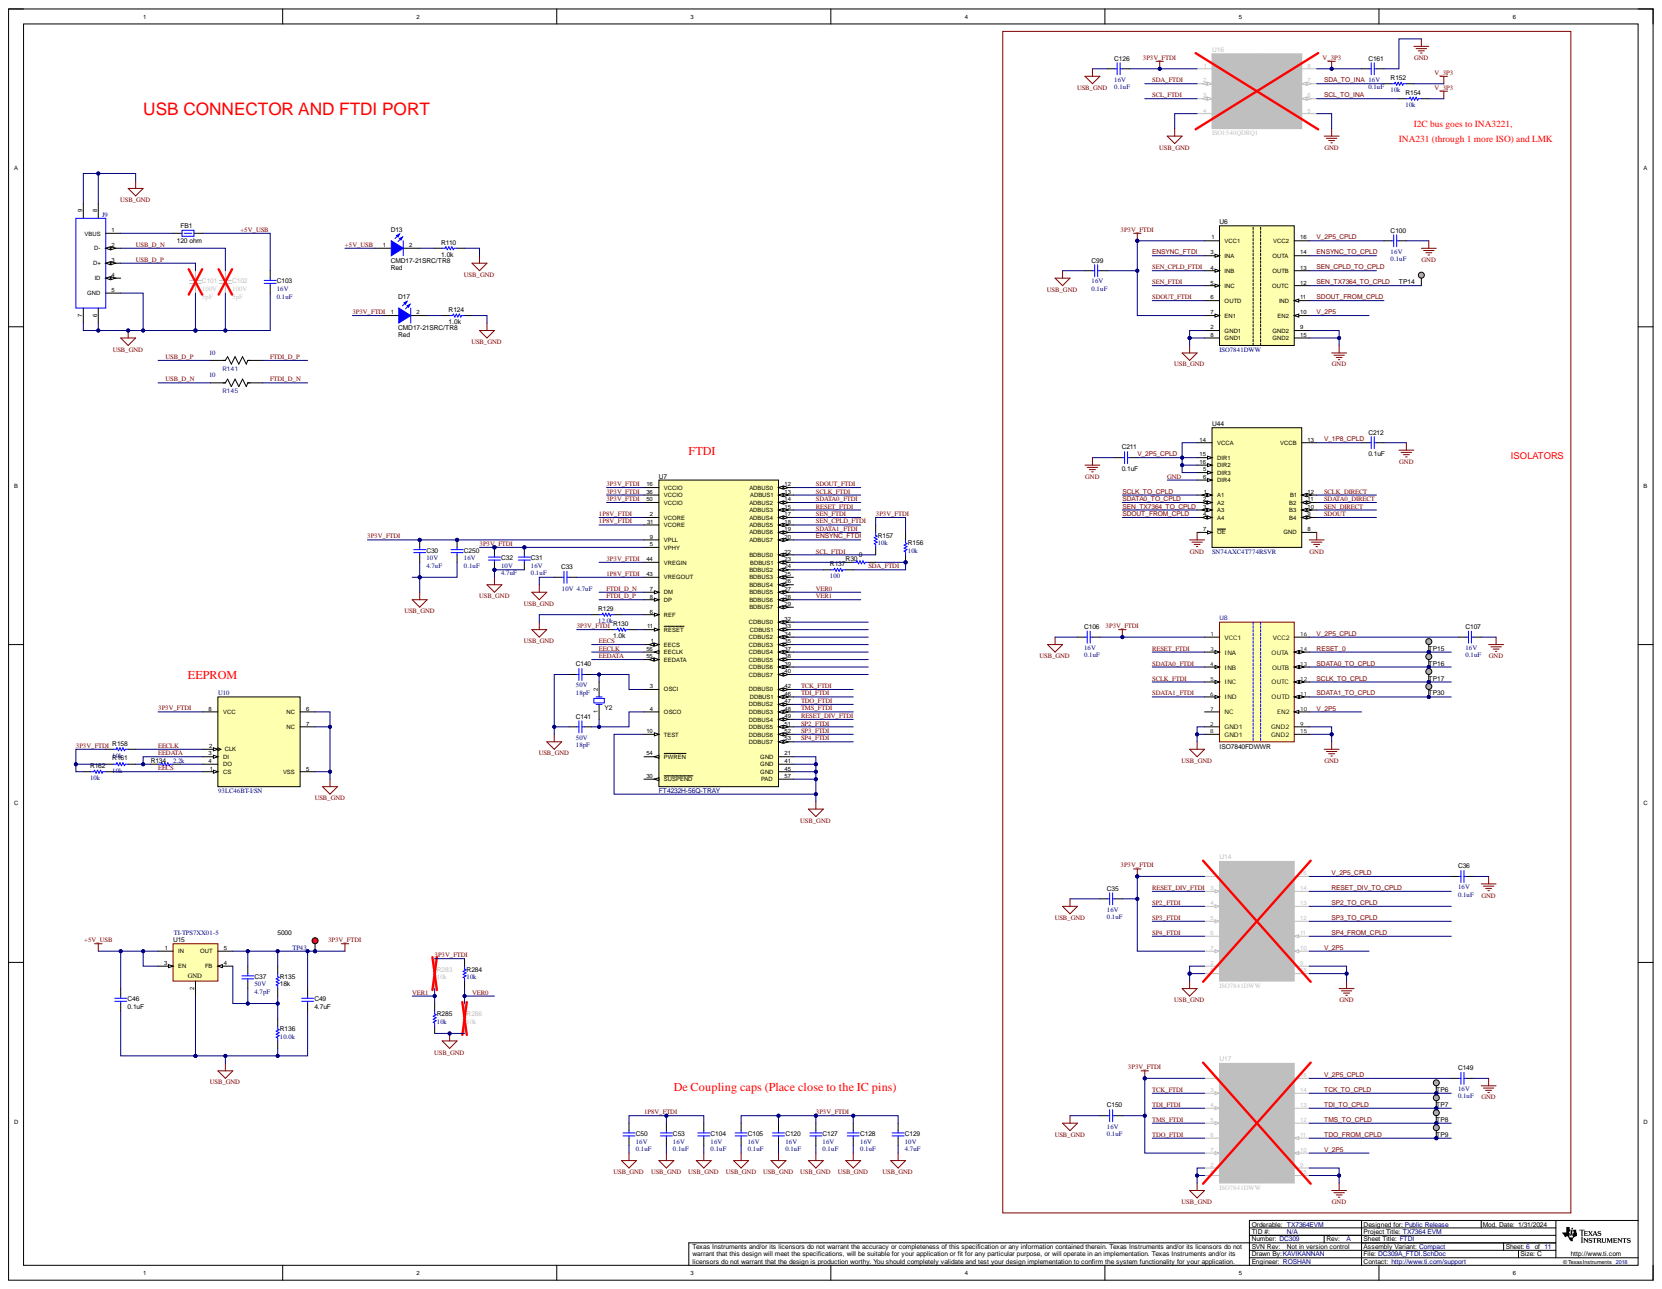
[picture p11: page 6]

USB CONNECTOR AND FTDI PORT

I2C bus goes to INA3221,
INA231 (through 1 more ISO) and LMK

De Coupling caps (Place close to the IC pins)

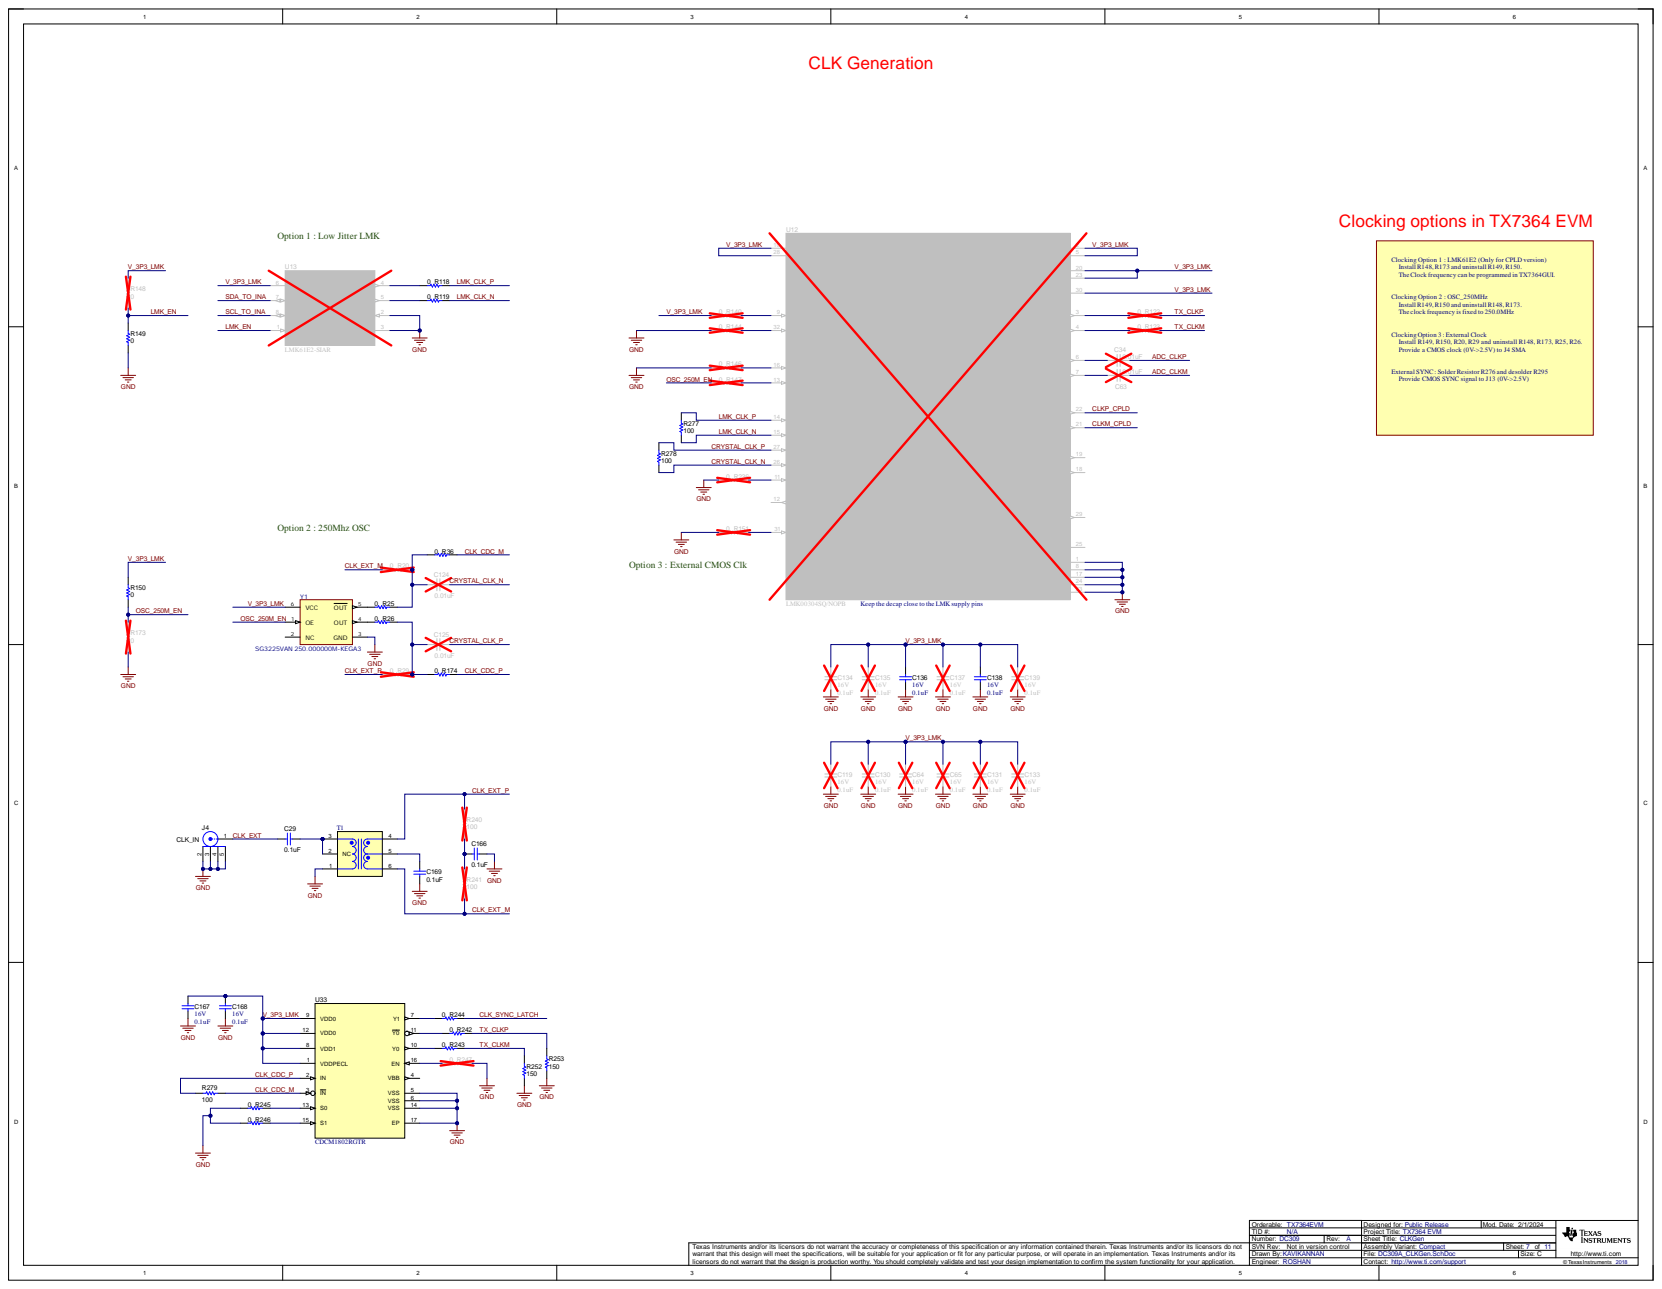
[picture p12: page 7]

Clocking options in TX7364 EVM

Option 1 : Low Jitter LMK

Clocking Option 1 : LMK61E2 (Only for CPLD version)
Install R148,R173 and uninstall R149,R150.
The Clock frequency can be programmed in TX7364GUI.

Clocking Option 2 : OSC_250MHz
Install R149,R150 and uninstall R148,R173.
The clock frequency is fixed to 250.0MHz

Clocking Option 3 : External Clock
Install R149, R150, R20, R29 and uninstall R148, R173, R25, R26.
Provide a CMOS clock (0V->2.5V) to J4 SMA

External SYNC: Solder Resistor R276 and desolder R295
Provide CMOS SYNC signal to J13 (0V->2.5V)

Option 3 : External CMOS Clk

Keep the decap close to the LMK supply pins

VDD0 12 | 0 R242 TX_CLKP

VDD1 8

VDDPECL 1

R279 CLK_CDC_M | IN 3

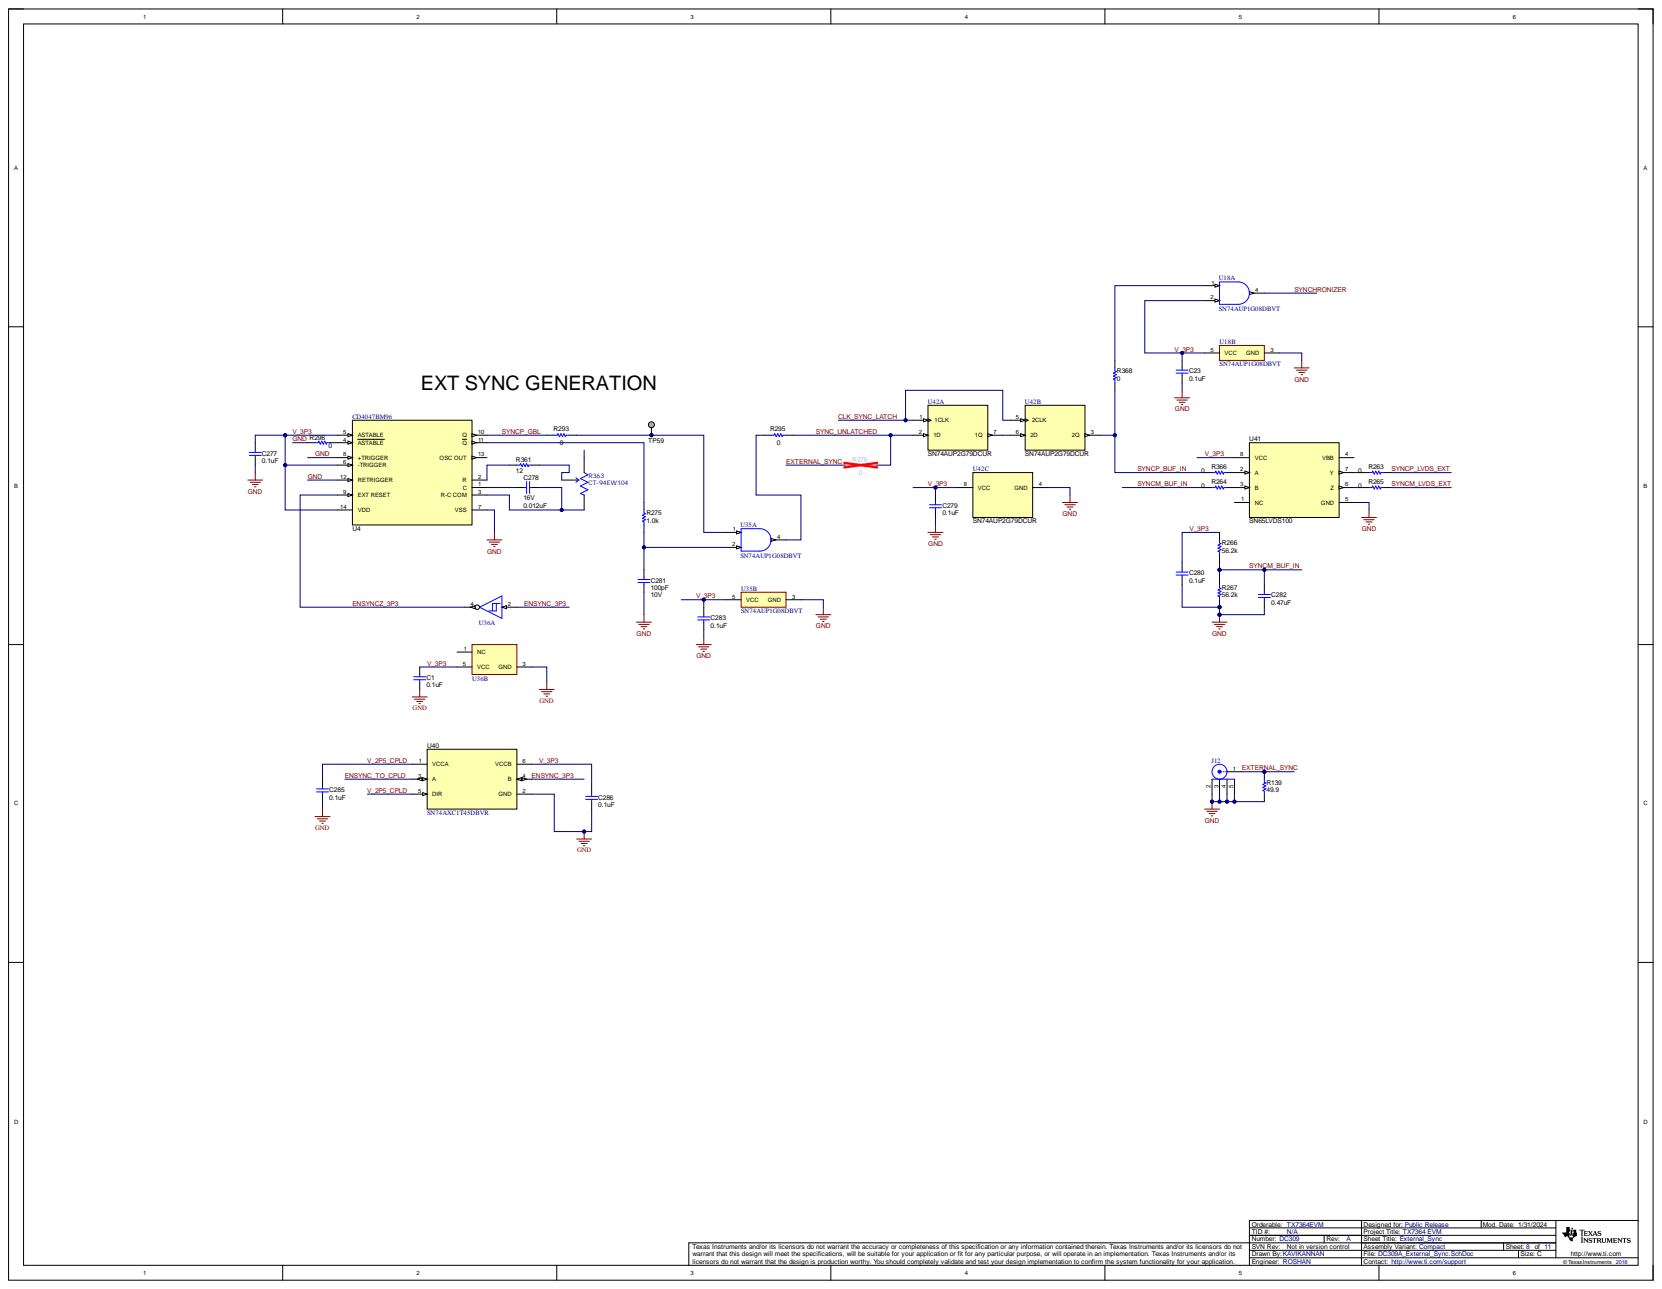
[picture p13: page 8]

GND R296 0 GND | +TRIGGER 8 -TRIGGER 6 | | R275 1.0k

GND | | RETRIGGER 12 EXT RESET 9

VDD 14

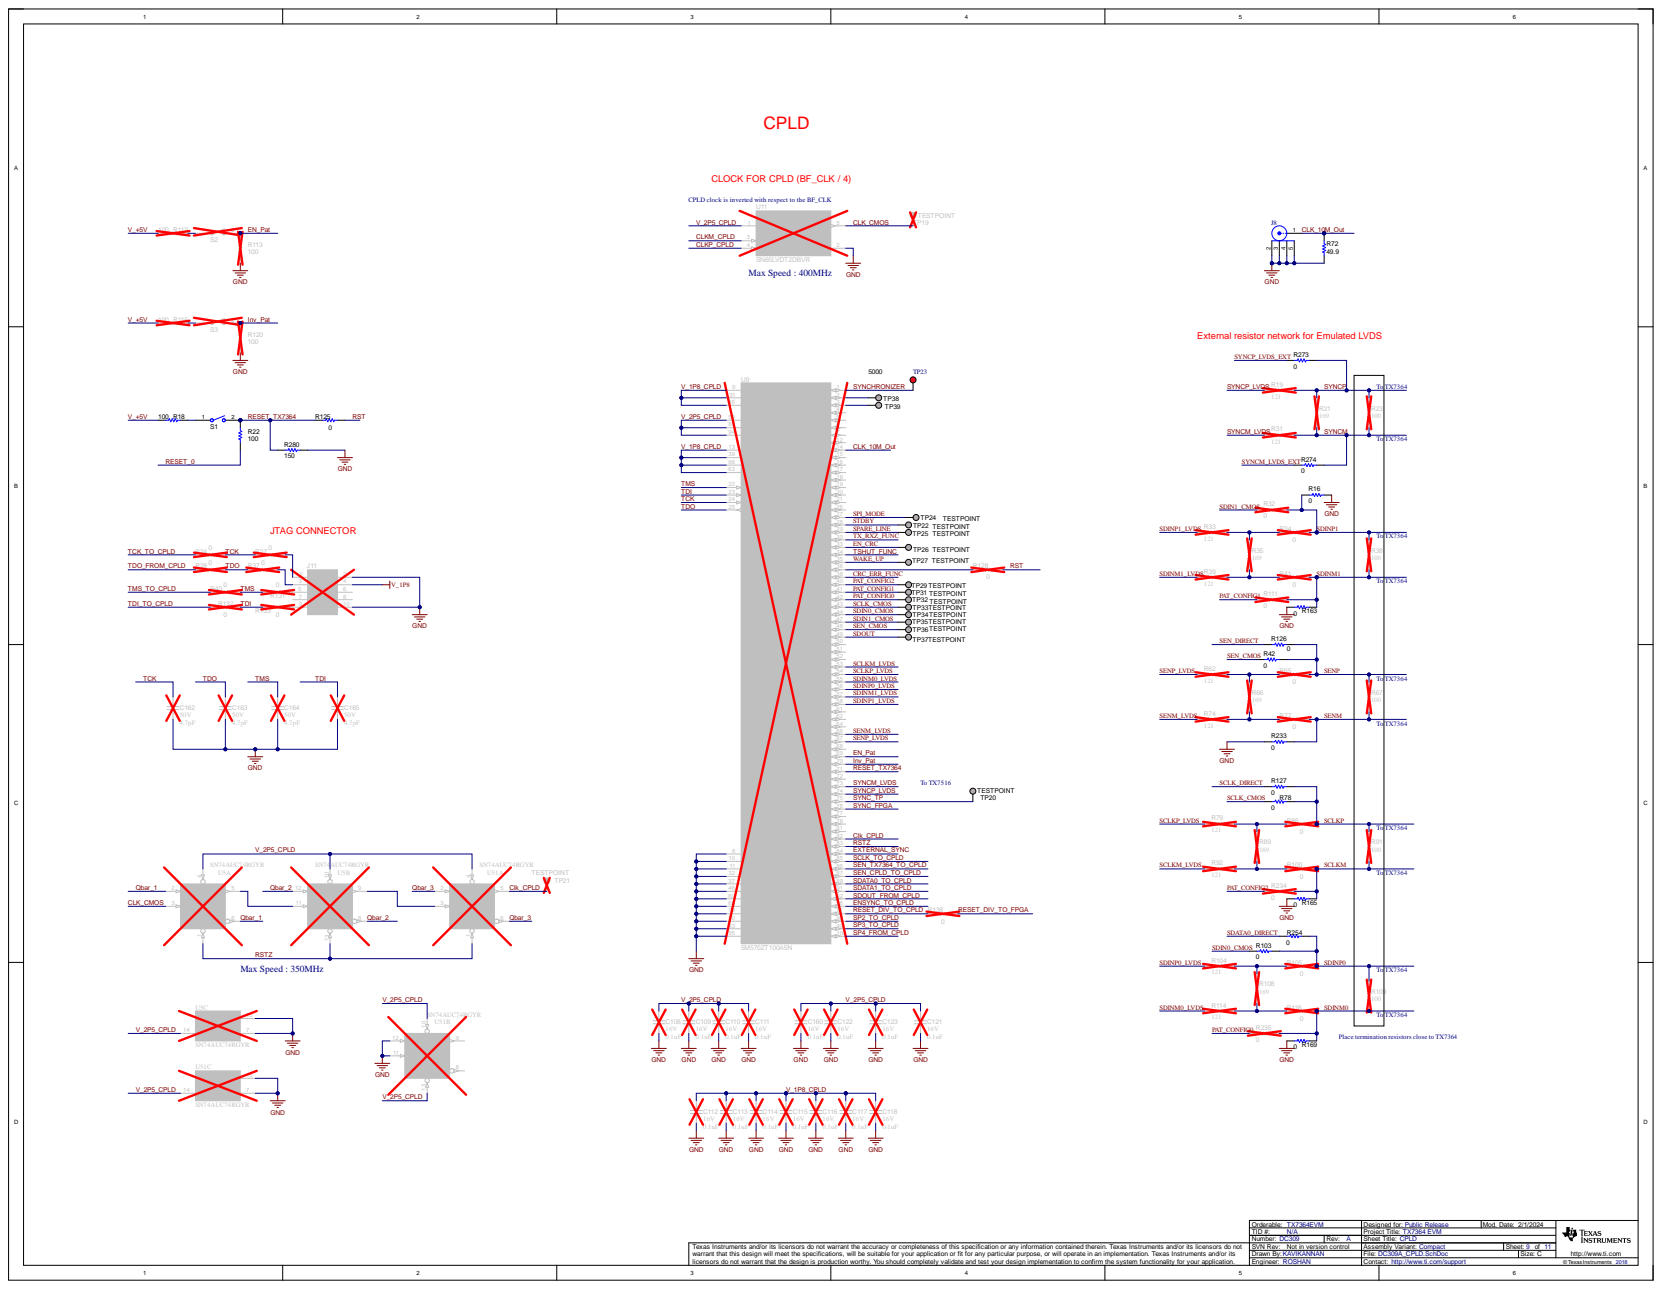
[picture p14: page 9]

CPLD clock is inverted with respect to the BF_CLK

External resistor network for Emulated LVDS

VCCIO1 31 | TP39
VCCIO1 45

Place termination resistors close to TX7364

CPLD

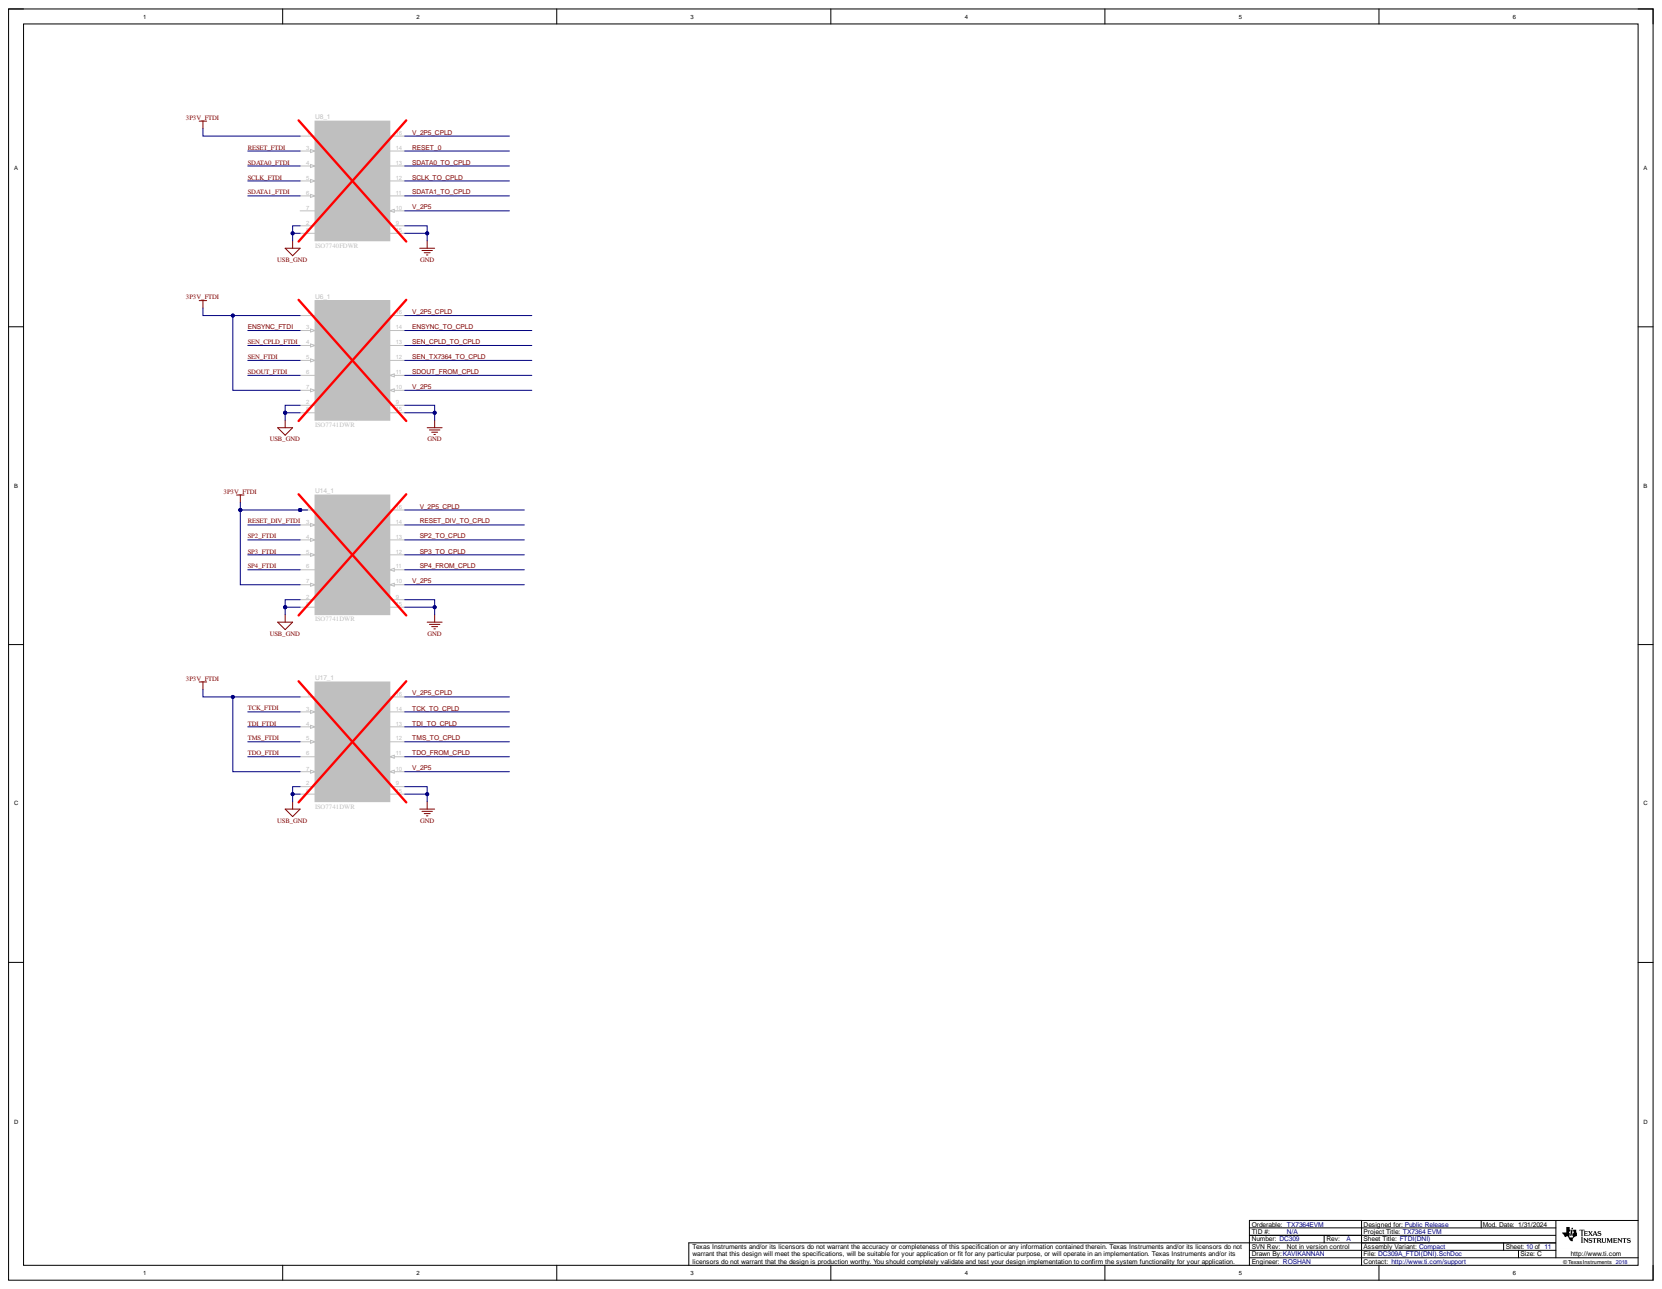
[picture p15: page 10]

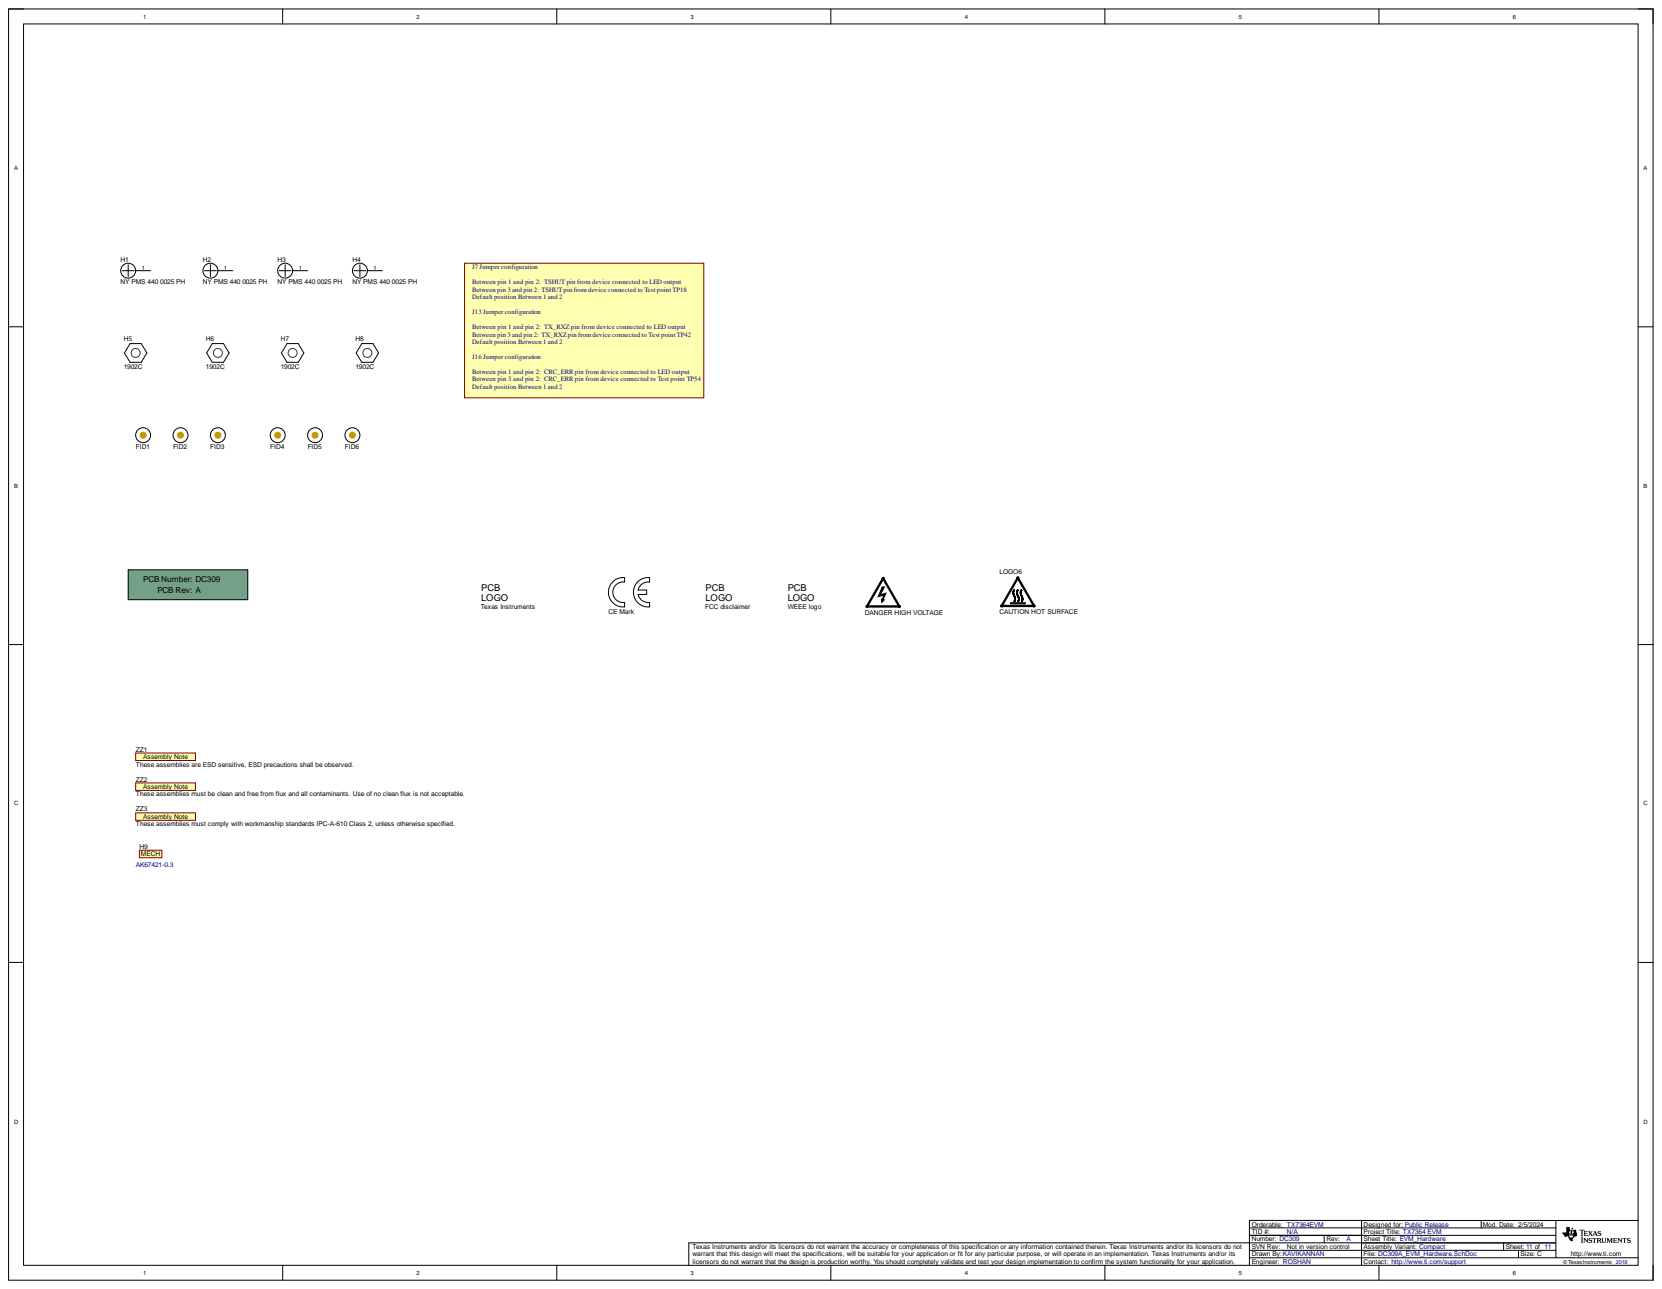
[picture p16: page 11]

Between pin 1 and pin 2: TSHUT pin from device connected to LED output
Between pin 3 and pin 2: TSHUT pin from device connected to Test point TP18
Default position Between 1 and 2

Between pin 1 and pin 2: TX_RXZ pin from device connected to LED output
Between pin 3 and pin 2: TX_RXZ pin from device connected to Test point TP42

Between pin 1 and pin 2: CRC_ERR pin from device connected to LED output
Between pin 3 and pin 2: CRC_ERR pin from device connected to Test point TP54

Assembly Note
These assemblies are ESD sensitive, ESD precautions shall be observed.

These assemblies must be clean and free from flux and all contaminants. Use of no clean flux is not acceptable.

These assemblies must comply with workmanship standards IPC-A-610 Class 2, unless otherwise specified.
